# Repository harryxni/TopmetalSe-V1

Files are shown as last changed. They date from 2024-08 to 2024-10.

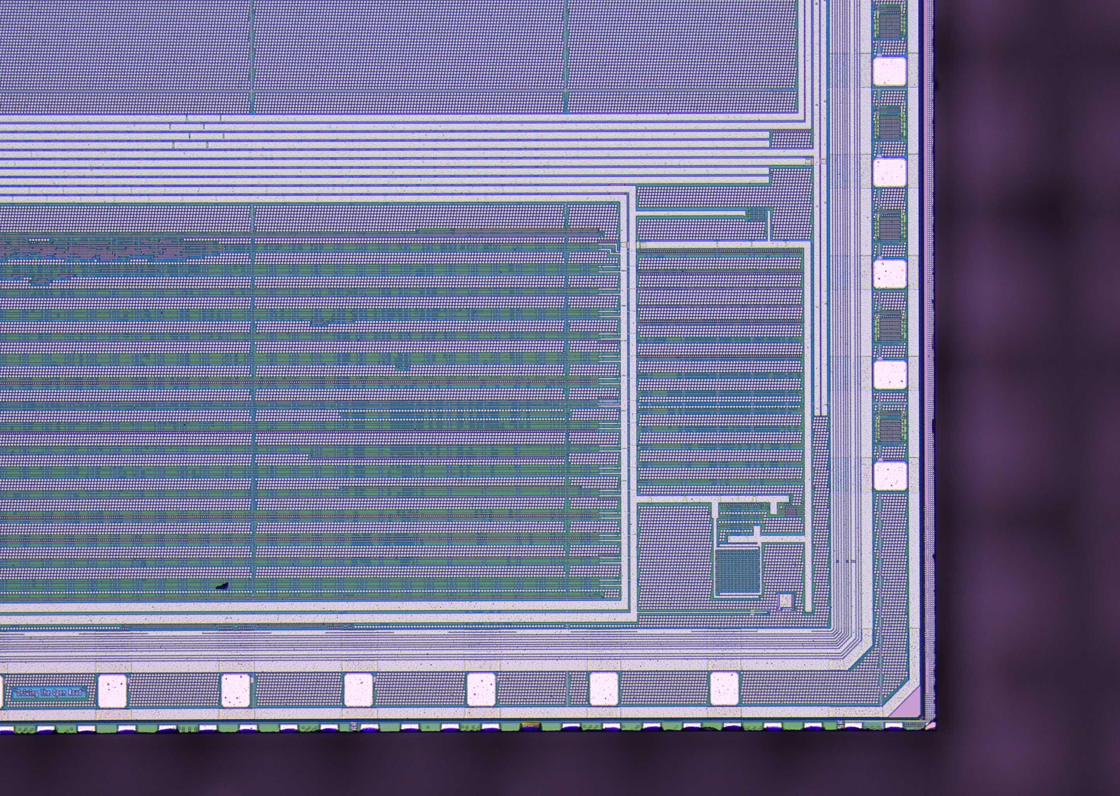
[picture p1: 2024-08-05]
Hardware/Images/chip_microscope_pictures/riscv.jpg

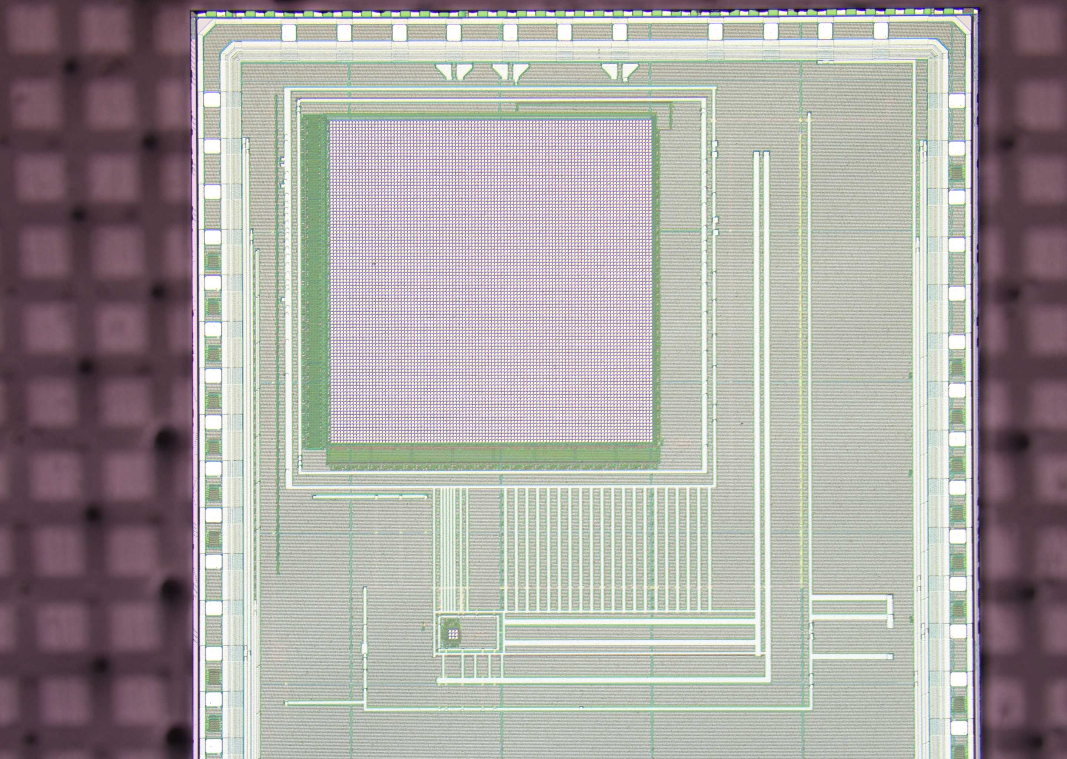
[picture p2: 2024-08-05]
Hardware/Images/chip_microscope_pictures/full.jpg

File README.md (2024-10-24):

# TopmetalSe-V1
This repo stores almost all of the info to run and understand the TopmetalSe

The directories here should be pretty self-explanatory honestly. 

If you want to learn how to run the chip, please look at Hardware and Firmware.

If you want to learn how well the chip performs and see examples, please look at Results.

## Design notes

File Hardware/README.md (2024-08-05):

# Hardware 
This directory contains the design files for using and testing the TopmetalSe.

## Test PCB, the UW Caravel Test Board
This board is the primary board used for testing as it contains all of the electronics necessary for running the chip.

A large part of this board is concerned with running the [caravel SOC](https://caravel-harness.readthedocs.io/en/latest/index.html), which is a part of the chip that we ultimatly do not use much. However, it is important to know that we can communicate with it, if necessary. It can also be useful to test I/O connections and make sure the chip is powered on/works as expected. As a result, much of this board is copied over from the [efabless caravel boards](https://github.com/efabless/caravel_board). A lot of the communication with the caravel SOC is done over USB via the FTDI chip and requires the clock to be on. For actual chip testing, please solder a jumper over J4 to turn the clock off to reduce the electronic noise.

The other part of the board is concerned with running the TopmetalSe, which happens in three categories: biasing, clocking and readout. 

The biasing of the chip is handled via the [Texas Instruments DAC 8568](https://www.ti.com/product/DAC8568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), which is an 8 Channel Digital to Analog Conveter. That is, we send digital commands and it outputs an analog voltage. The digital communication part is handled by an external FPGA, and the commands are generated via [software bit banging](https://github.com/selena0vbb/TopmetalSe_Sequencer/blob/main/util/DAC_control.py). These analog voltages are used as a bias either to source/sink a current or as a voltage bias on a transistor gate. 

The clocking of the chip is entirely handled by the external FPGAa and its firmware, so please look elsewhere for that. In the PCB design files, there are level shifters on the clocking signals to shift from the FPGA 3.3V signals to what I had assumed to be the caravel's 1.8V logic levels. However, the caravel harness actually expects 3.3V signals, so these level shifters are not soldered on and a jumper wire is used to make these connections.

There are two output signals coming from the TopmetalSe, an output for the large array (LA) and an output for the small array (SA). Both of these signals are readout using an opamp on the PCB. 

## Carrier Boards
To connect to the chip, we use a collection of adapter boards. This allows us to hotswap in any chip we want for testing. Now, the topmetalSe comes in a variety of packages, each of which has its own unique carrier board to accomdate the package. The carrier board is then plugged into the test board via 50 mil pins.

__One design fault is that the carriers can easily be plugged in incorrectly, causing undesired shorts. Please double check the pins and lined up correctly and in the correct orientation, as the header pins are symmetric. This applies to all carrier boards but the M.2 adapter.__

### M.2 Adapter Board
EFabless provided us with many QFN packaged chips. QFN, or quad flat no-leads, is an industry standard package for chips. Inside, chips are wire bonded to the frame and then encapsulated in plastic. This means that the QFN packages provide us with all the electrical capabilities, but none of the charge-sensing aspects of our device. __Please use these QFN packages to test and play around with learning to run the circuit__. Because we have so many and everything is encapsulated, there is very little chance of damaging these devices.

The QFN packages are/can be soldered onto a M.2 breakout board. EFabless provides the (design files)[https://github.com/efabless/caravel_board/tree/main/hardware/breakout/caravel-M.2-card-QFN] for these, so please look there if you need to. If you need more, the QFN packages must be soldered onto more M.2 breakouts.

The M.2 breakout boards can be attached to our test board via the M.2 adapter board.

### Wire Bonded

For charge-sensing, we must use the bare dies. The wire bonded carrier boards are pretty simple, as the bond pads go in the same order as the bond pads on the chip. The one key is that __the wire bonded board must be ENEPIG coated (not ENIG)__. If you order more, please make sure of this.

### Flip Chip

### aSe Flip Chip

## FPGA
For the FPGA, we use an external [BASYS3 Board](https://digilent.com/shop/basys-3-artix-7-fpga-trainer-board-recommended-for-introductory-users/). It is connected to the test board via PMOD connectors. Now, there is a mistake in the PCB design where the PMOD headers are actually flipped, so you must be careful to flip the PMOD connectors. Please see the PCB layout for this as well as the labels on the PCB to make sure things are aligned (ie Pin 1 to Pin 1). The firmware for the FPGA is discussed elsewhere.

## Sapphire Interposer
In flip chip packages, the chip is bonded to a flat piece known as the interposer. It is made with a 200/300 um thick piece of sapphire, which has conductive traces patterned and deposited onto it (usually O(100) nm of Al and Au). The side with traces on it is the bottom side. The top side is used for aSe Deposition and contains a conductive mesh. There is also a window opening where the pixel array is, which we typically laser cut.

## Electronic Equipment

## Mechanical Parts

## TopmetalSe Design Files
The majority of the design files for the TopmetalSe-V1 are contained in a [separate repo](https://github.com/harryxni/TopMetalSe-OpenMPW6). I include some general files in this repo as a reference.

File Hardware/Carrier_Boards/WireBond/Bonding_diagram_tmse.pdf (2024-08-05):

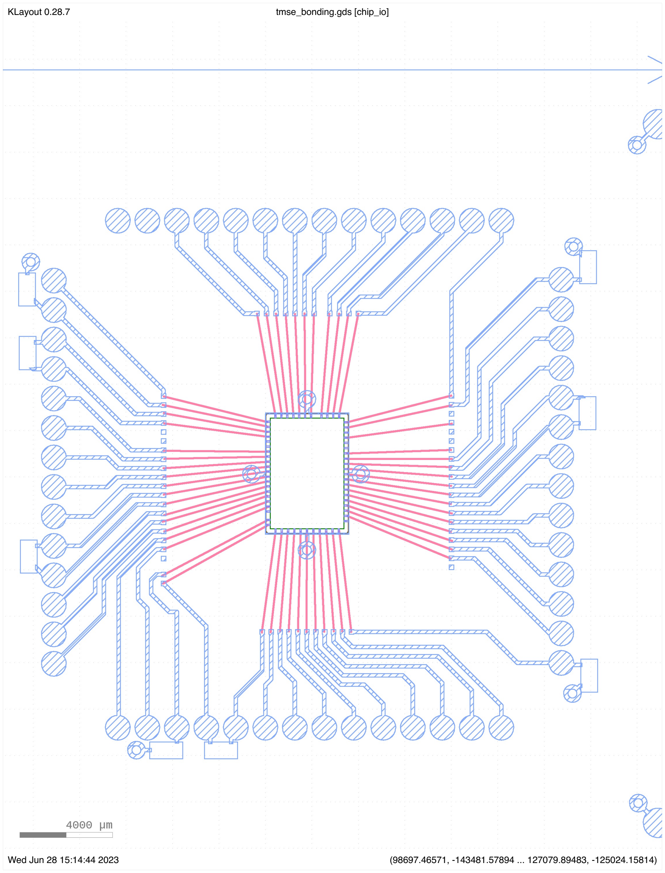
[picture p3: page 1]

KLayout 0.28.7 | tmse_bonding.gds [chip_io]
Wed Jun 28 15:14:44 2023 | (98697.46571, -143481.57894 ... 127079.89483, -125024.15814)

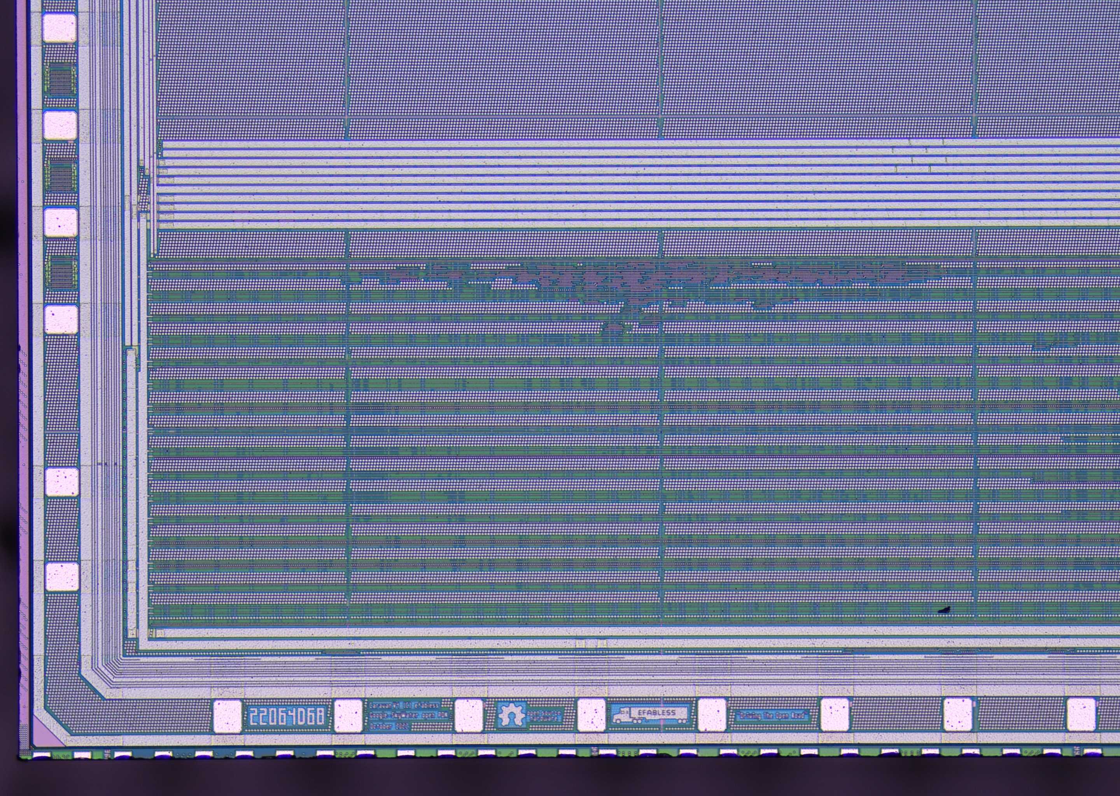
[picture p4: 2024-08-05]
Hardware/Images/chip_microscope_pictures/corner_pads.jpg

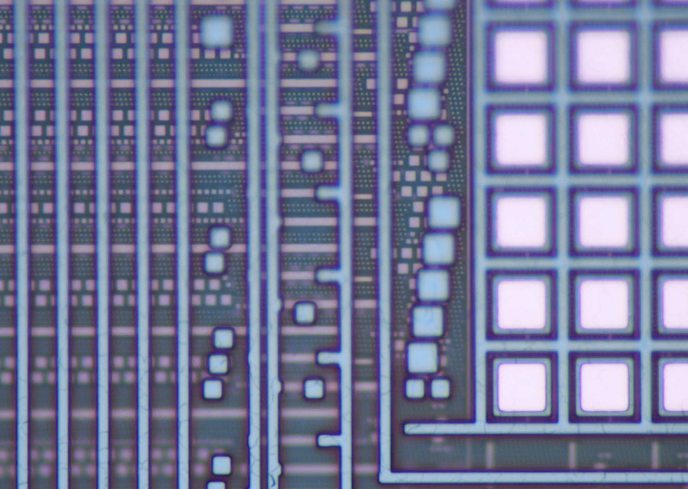
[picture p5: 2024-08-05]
Hardware/Images/chip_microscope_pictures/corner_large.jpg

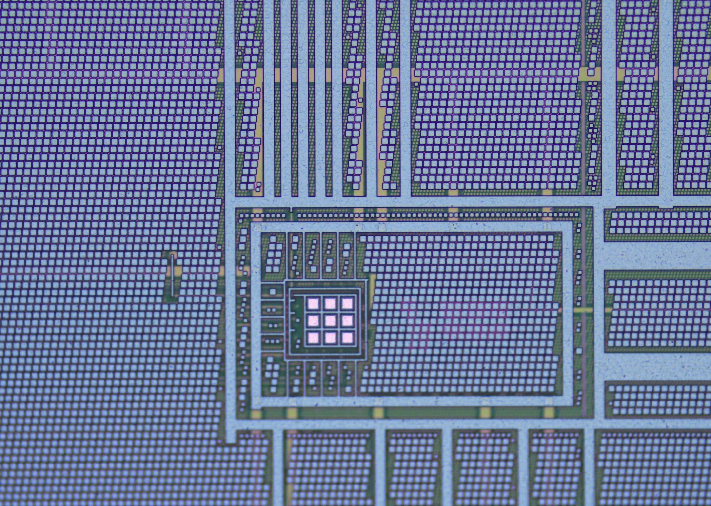
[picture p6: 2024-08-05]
Hardware/Images/chip_microscope_pictures/small_array.jpg

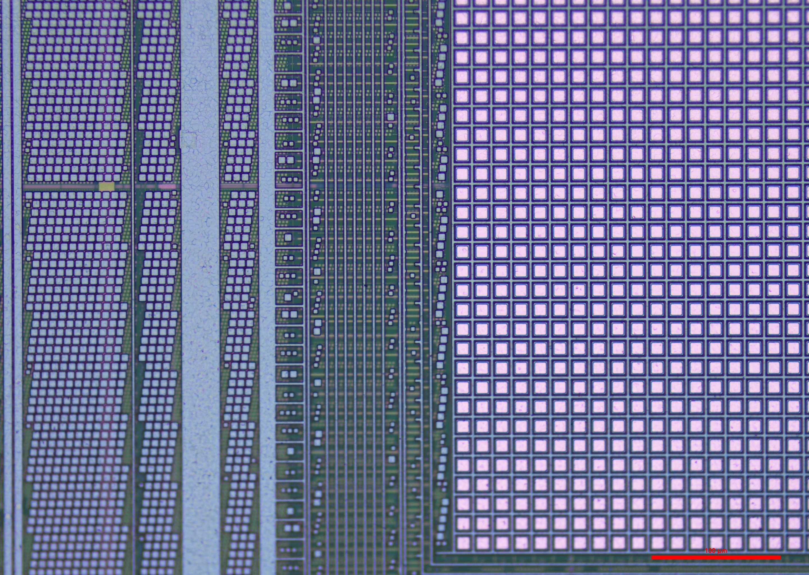
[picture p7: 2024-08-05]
Hardware/Images/chip_microscope_pictures/large_pixels.jpg

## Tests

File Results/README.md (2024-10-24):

# Results

In this directory, I am including the results of testing that we have done with the TopmetalSe.

## Guard Ring Pulsing for Charge Sensitive Amplifiers
An example of how we characterize the in-pixel charge sensitive amplifiers. This for a single pixel in a notebook.

We demonstrate the low-noise of these pixels.

## Visible Light Imaging
Testing the ability of the TopmetalSe to actually take images.

## Alpha Event Imaging
This result shows the TopmetalSe's ability to image external charge that lands on the pixel electrodes.

## Photoelectric Effect Imaging
Measuring the pixel array's collection efficiency by generating and measuring a calibrated amount of electrons external to the pixel array.

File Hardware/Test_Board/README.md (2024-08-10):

# Annotated PCB

In the annotated pcb image file, I have added some markers to explain any fixes that need to be made to the current test board. These are either where jumper cables must be soldered onto, or any components which should not be present.

On the left side of the board, the level shifters U12-U26 should not be used/soldered on. Instead, a jumper cable should be soldered between pads 3 and 4.

D4 should not be soldered on simply to remove a strong source of light which could ionize charge in the pixel array. It can useful to know if power is being supplied correctly, so use it in any initial testing phases. But, it should not be present for serious testing.

LA_Row_Clk should always be used and not Ser Tx (jumpered across).

VCCD should be connected to VCCD2 under the carrier board, so there should be a jumper wire between pins 43 and 27.

R23, R25 and R27 should not be present to prevent current flow along the voltage bias lines.

LDAC bar should always be jumpered.

The signals names for ROW and COL are actually switched. This is fixed in the FPGA software which controls these lines, but should be noted for any future iterations.

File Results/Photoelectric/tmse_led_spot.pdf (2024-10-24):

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

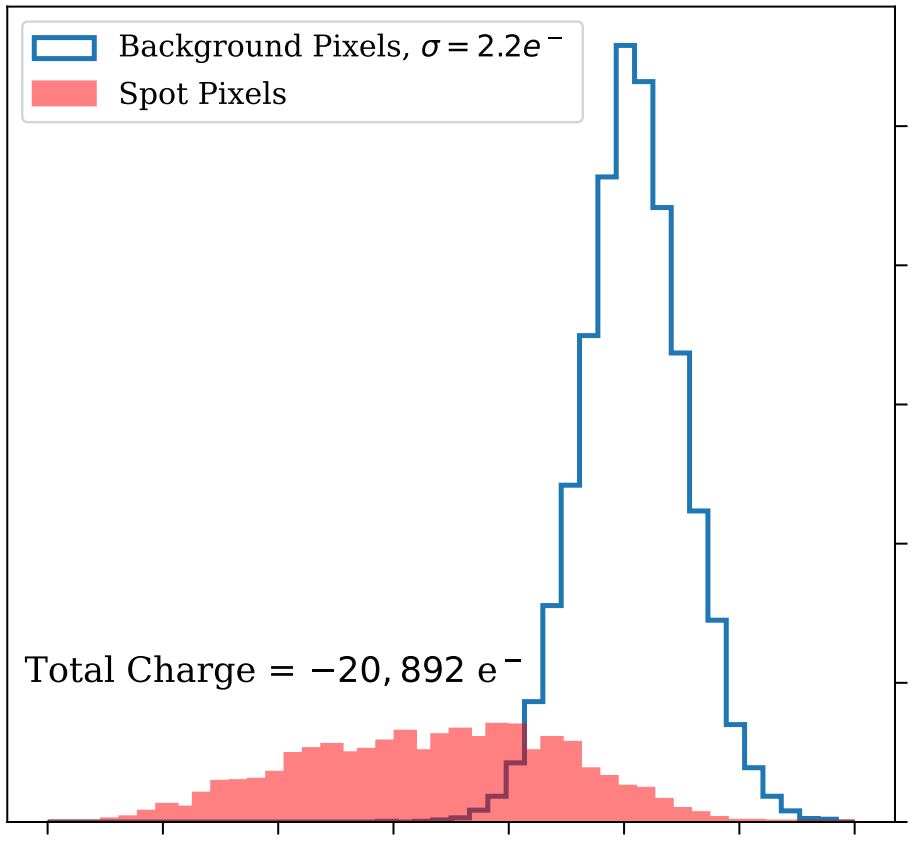
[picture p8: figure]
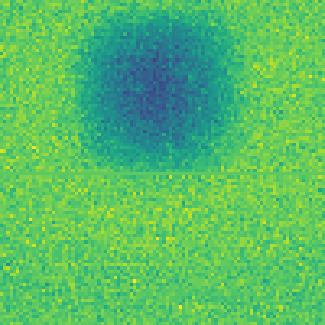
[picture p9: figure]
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

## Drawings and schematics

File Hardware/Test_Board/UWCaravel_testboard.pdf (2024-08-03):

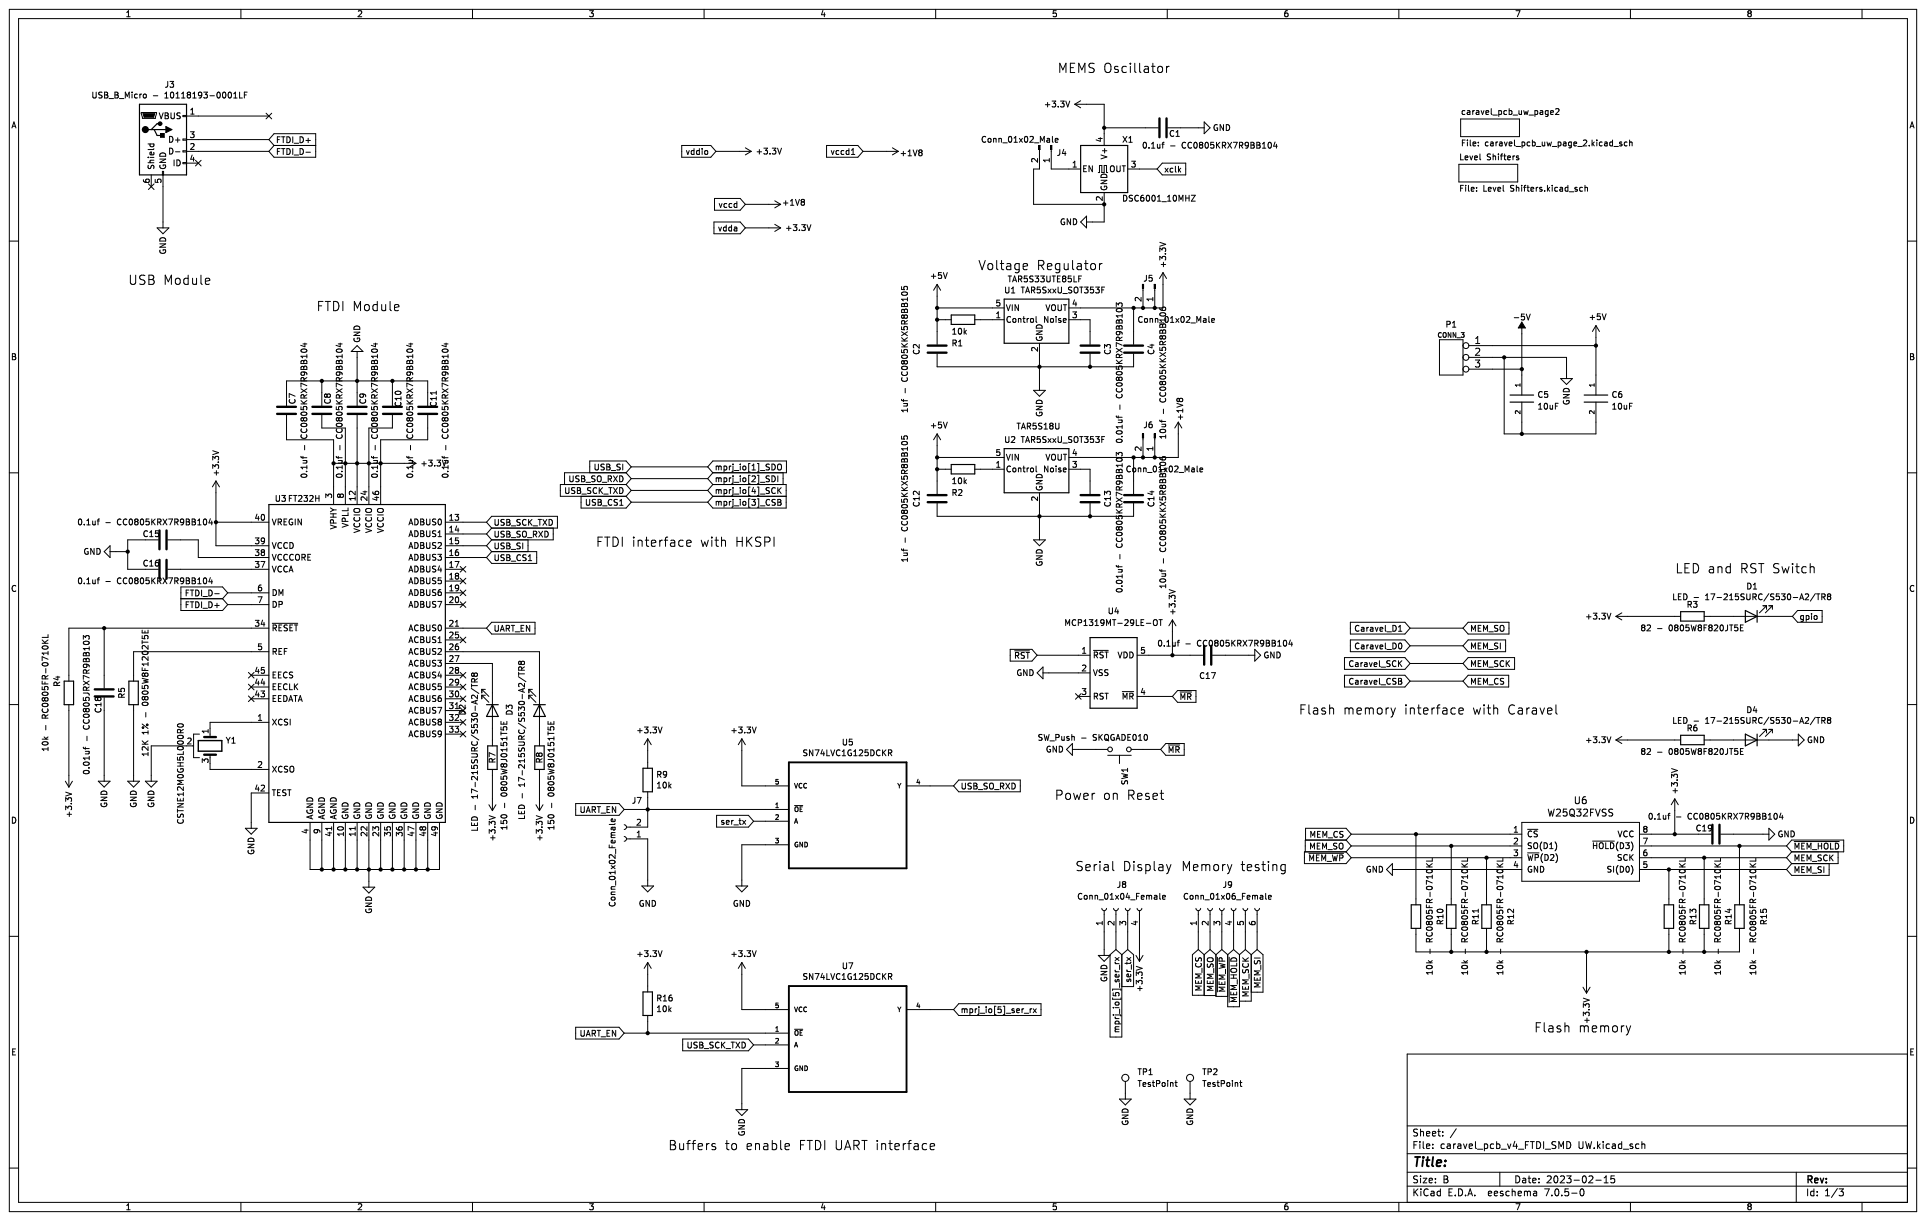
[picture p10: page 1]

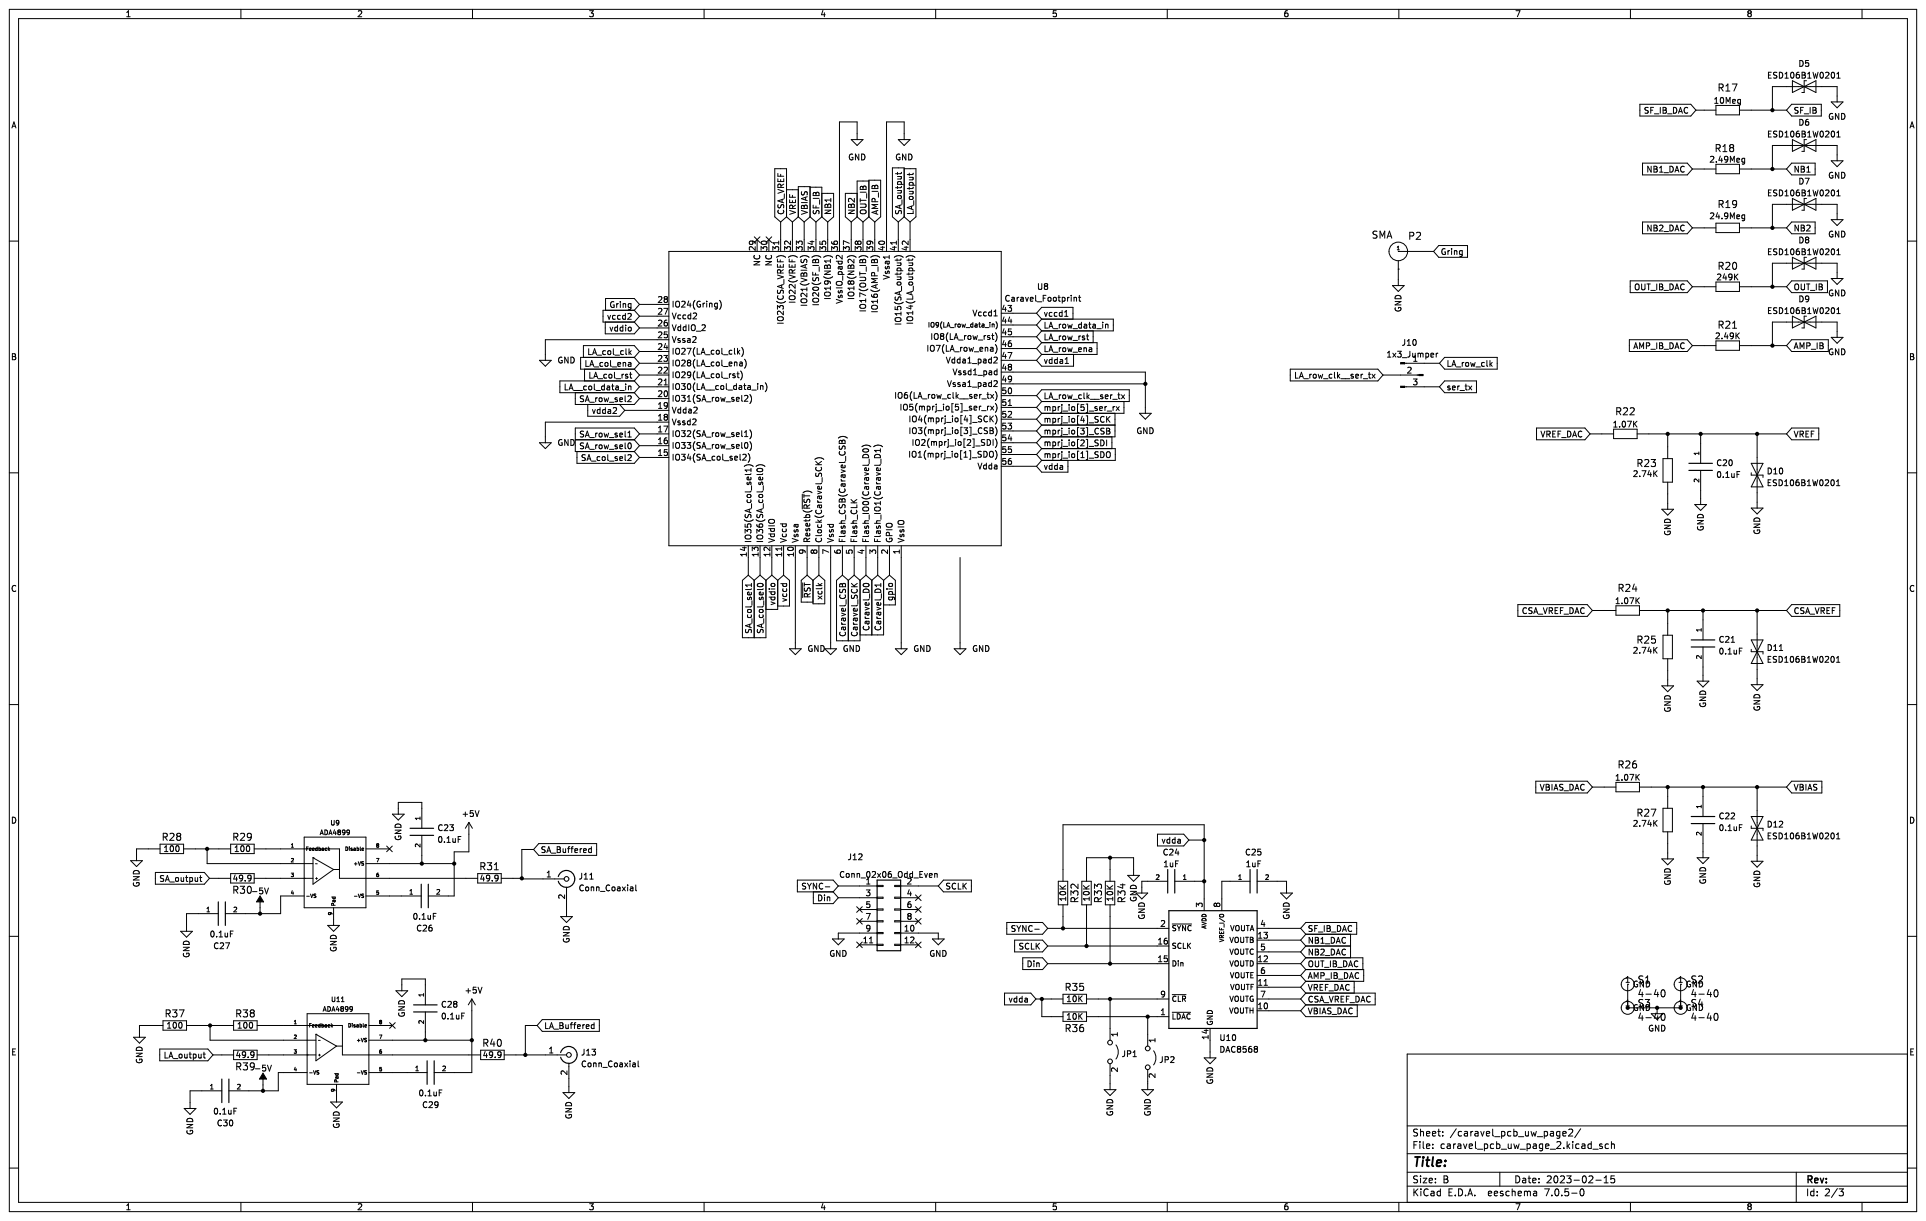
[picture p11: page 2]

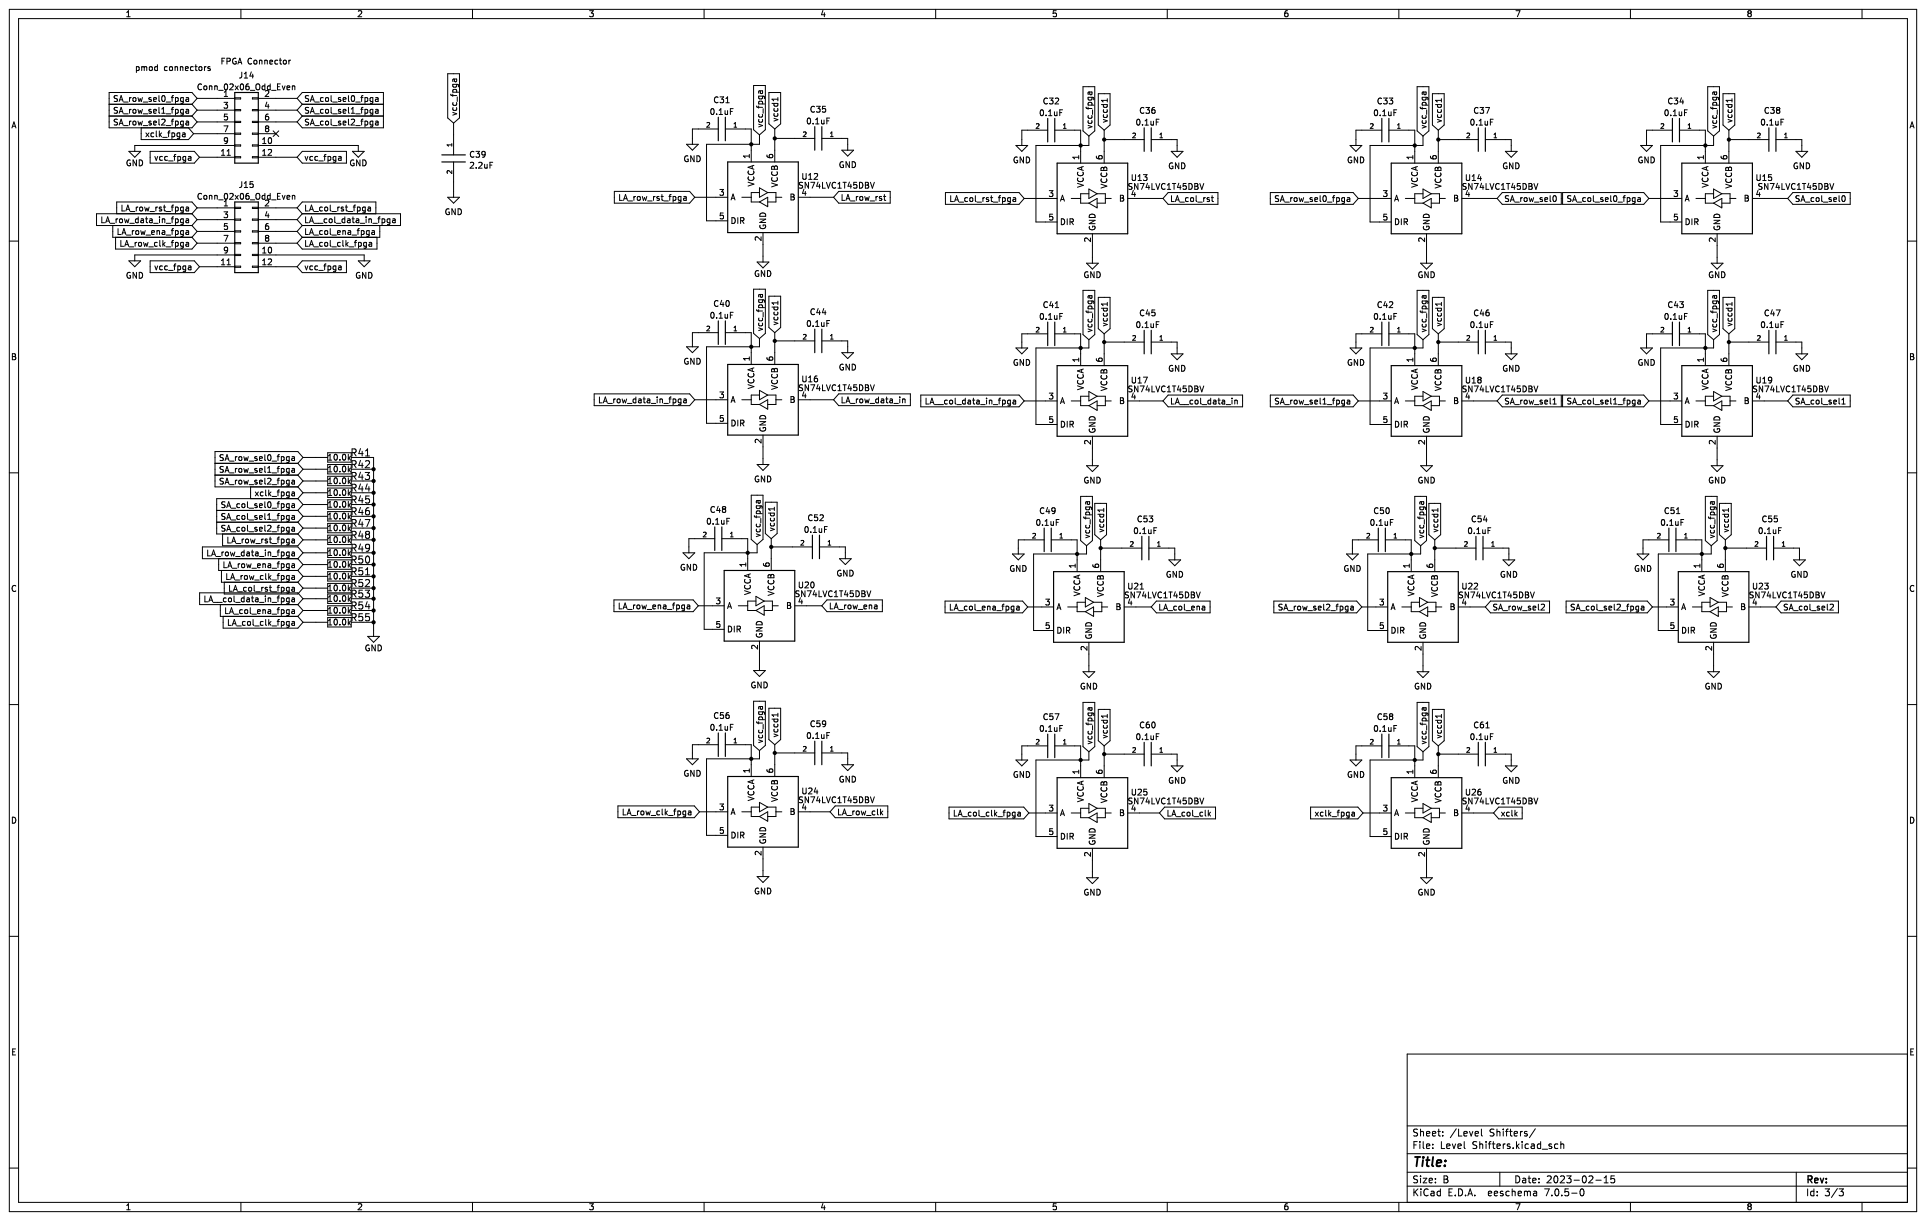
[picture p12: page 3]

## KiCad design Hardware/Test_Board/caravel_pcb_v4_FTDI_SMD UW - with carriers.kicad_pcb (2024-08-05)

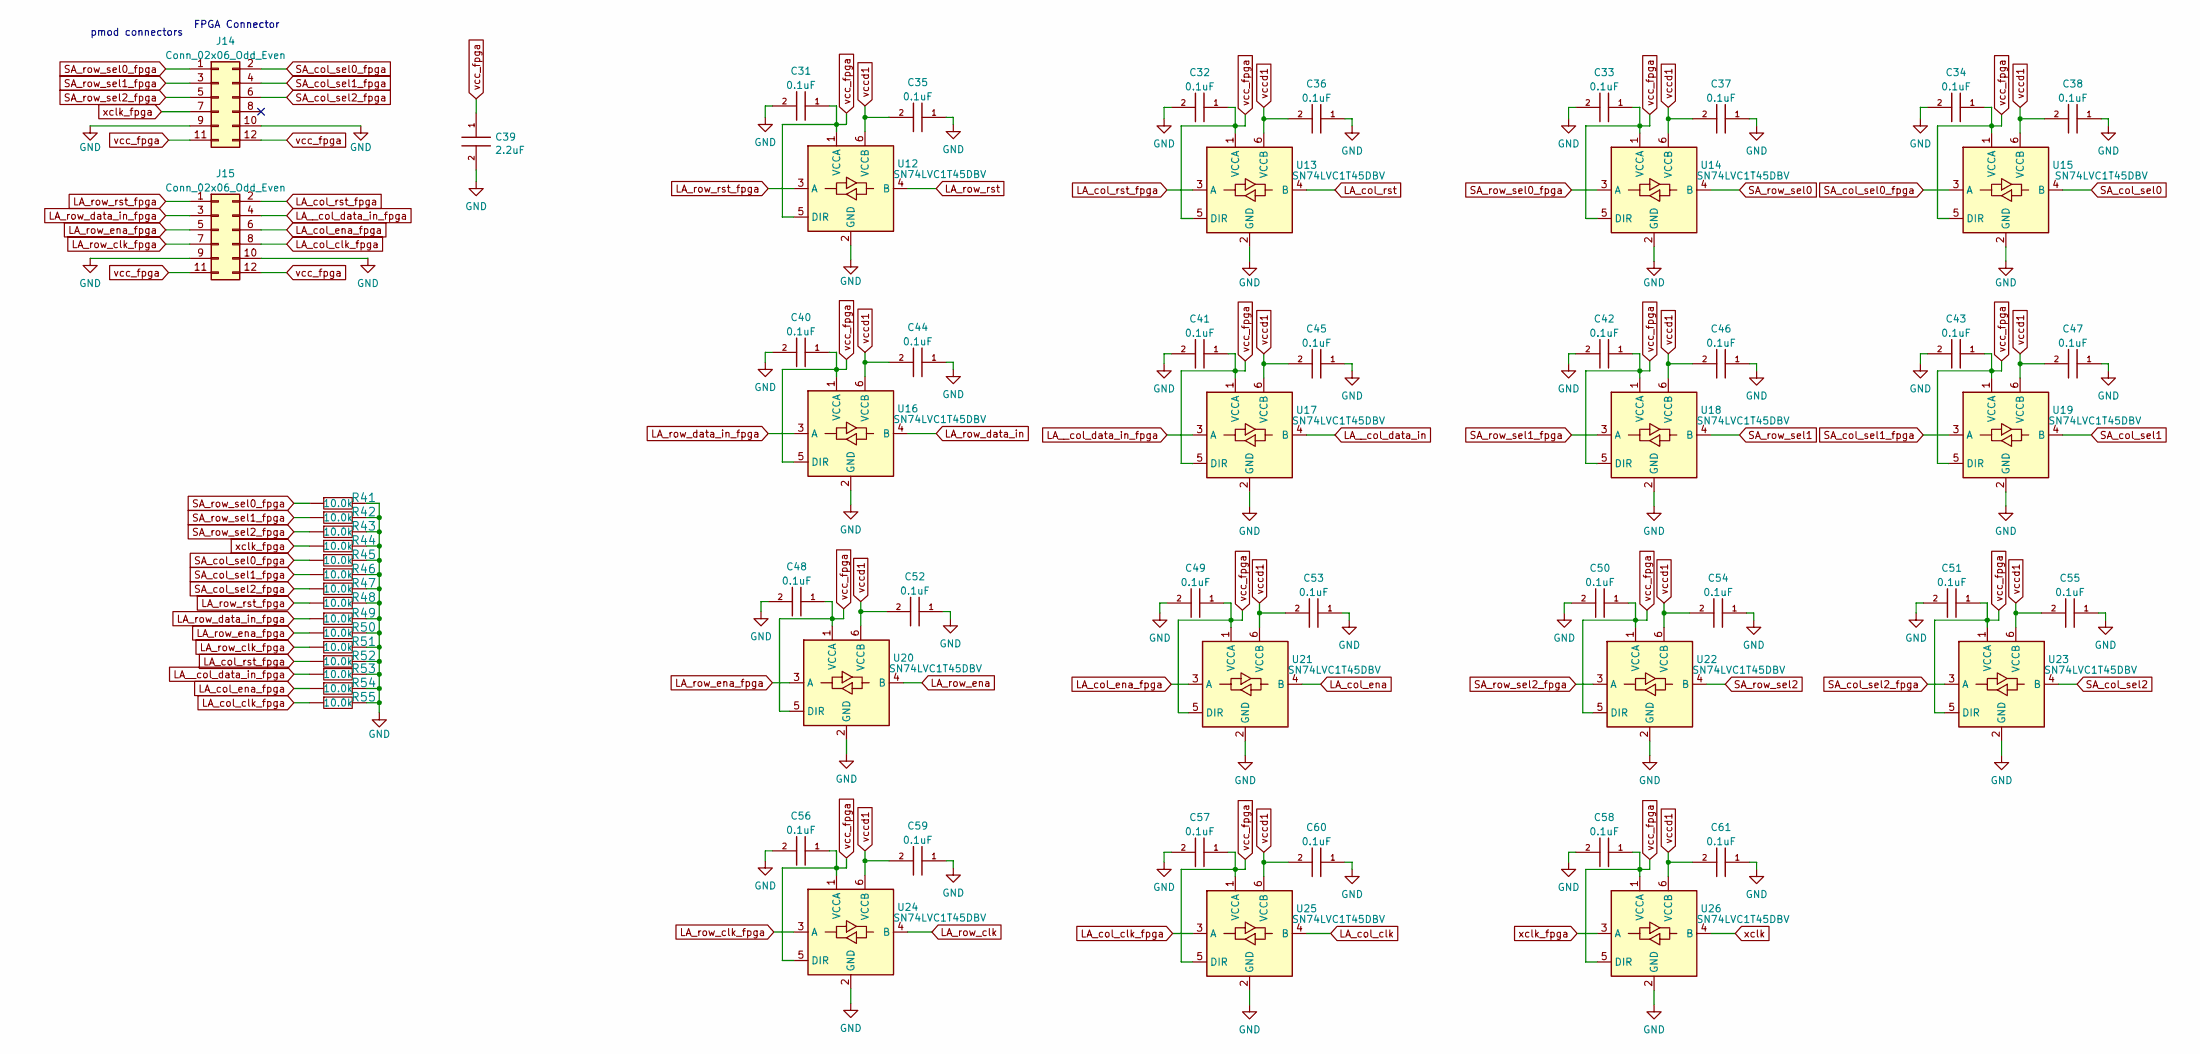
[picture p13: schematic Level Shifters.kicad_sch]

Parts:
C31, C32, C33, C34, C35, C36, C37, C38, C40, C41, C42, C43, C44, C45, C46, C47, C48, C49, C50, C51, C52, C53, C54, C55, C56, C57, C58, C59, C60, C61: 0.1uF; SM0603
C39: 2.2uF; SM0603
J14, J15: Conn_02x06_Odd_Even; PinHeader_2x06_P2.54mm_Horizontal
R41, R42, R43, R44, R45, R46, R47, R48, R49, R50, R51, R52, R53, R54, R55: 10.0k; SM0603
U12, U13, U14, U15, U16, U17, U18, U19, U20, U21, U22, U23, U24, U25, U26: SN74LVC1T45DBV; SOT-23-6

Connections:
LA__col_data_in: U17.4 (B); also elsewhere on the board
LA__col_data_in_fpga: J15.4, R53.1, U17.3 (A)
LA_col_clk: U25.4 (B); also elsewhere on the board
LA_col_clk_fpga: J15.8, R55.1, U25.3 (A)
LA_col_ena: U21.4 (B); also elsewhere on the board
LA_col_ena_fpga: J15.6, R54.1, U21.3 (A)
LA_col_rst: U13.4 (B); also elsewhere on the board
LA_col_rst_fpga: J15.2, R52.1, U13.3 (A)
LA_row_clk: U24.4 (B); also elsewhere on the board
LA_row_clk_fpga: J15.7, R51.1, U24.3 (A)
LA_row_data_in: U16.4 (B); also elsewhere on the board
LA_row_data_in_fpga: J15.3, R49.1, U16.3 (A)
LA_row_ena: U20.4 (B); also elsewhere on the board
LA_row_ena_fpga: J15.5, R50.1, U20.3 (A)
LA_row_rst: U12.4 (B); also elsewhere on the board
LA_row_rst_fpga: J15.1, R48.1, U12.3 (A)
SA_col_sel0: U15.4 (B); also elsewhere on the board
SA_col_sel0_fpga: J14.2, R45.1, U15.3 (A)
SA_col_sel1: U19.4 (B); also elsewhere on the board
SA_col_sel1_fpga: J14.4, R46.1, U19.3 (A)
SA_col_sel2: U23.4 (B); also elsewhere on the board
SA_col_sel2_fpga: J14.6, R47.1, U23.3 (A)
SA_row_sel0: U14.4 (B); also elsewhere on the board
SA_row_sel0_fpga: J14.1, R41.1, U14.3 (A)
SA_row_sel1: U18.4 (B); also elsewhere on the board
SA_row_sel1_fpga: J14.3, R42.1, U18.3 (A)
SA_row_sel2: U22.4 (B); also elsewhere on the board
SA_row_sel2_fpga: J14.5, R43.1, U22.3 (A)
vcc_fpga: C31.1, C32.1, C33.1, C34.1, C39.1, C40.1, C41.1, C42.1, C43.1, C48.1, C49.1, C50.1, C51.1, C56.1, C57.1, C58.1, J14.11, J14.12, J15.11, J15.12, U12.1 (VCCA), U12.5 (DIR), U13.1 (VCCA), U13.5 (DIR), U14.1 (VCCA), U14.5 (DIR), U15.1 (VCCA), U15.5 (DIR), U16.1 (VCCA), U16.5 (DIR), U17.1 (VCCA), U17.5 (DIR), U18.1 (VCCA), U18.5 (DIR), U19.1 (VCCA), U19.5 (DIR), U20.1 (VCCA), U20.5 (DIR), U21.1 (VCCA), U21.5 (DIR), U22.1 (VCCA), U22.5 (DIR), U23.1 (VCCA), U23.5 (DIR), U24.1 (VCCA), U24.5 (DIR), U25.1 (VCCA), U25.5 (DIR), U26.1 (VCCA), U26.5 (DIR)
vccd: C35.2, C36.2, C37.2, C38.2, C44.2, C45.2, C46.2, C47.2, C52.2, C53.2, C54.2, C55.2, C59.2, C60.2, C61.2, U12.6 (VCCB), U13.6 (VCCB), U14.6 (VCCB), U15.6 (VCCB), U16.6 (VCCB), U17.6 (VCCB), U18.6 (VCCB), U19.6 (VCCB), U20.6 (VCCB), U21.6 (VCCB), U22.6 (VCCB), U23.6 (VCCB), U24.6 (VCCB), U25.6 (VCCB), U26.6 (VCCB); also elsewhere on the board
xclk: U26.4 (B); also elsewhere on the board
xclk_fpga: J14.7, R44.1, U26.3 (A)

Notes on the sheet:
pmod connectors
FPGA Connector

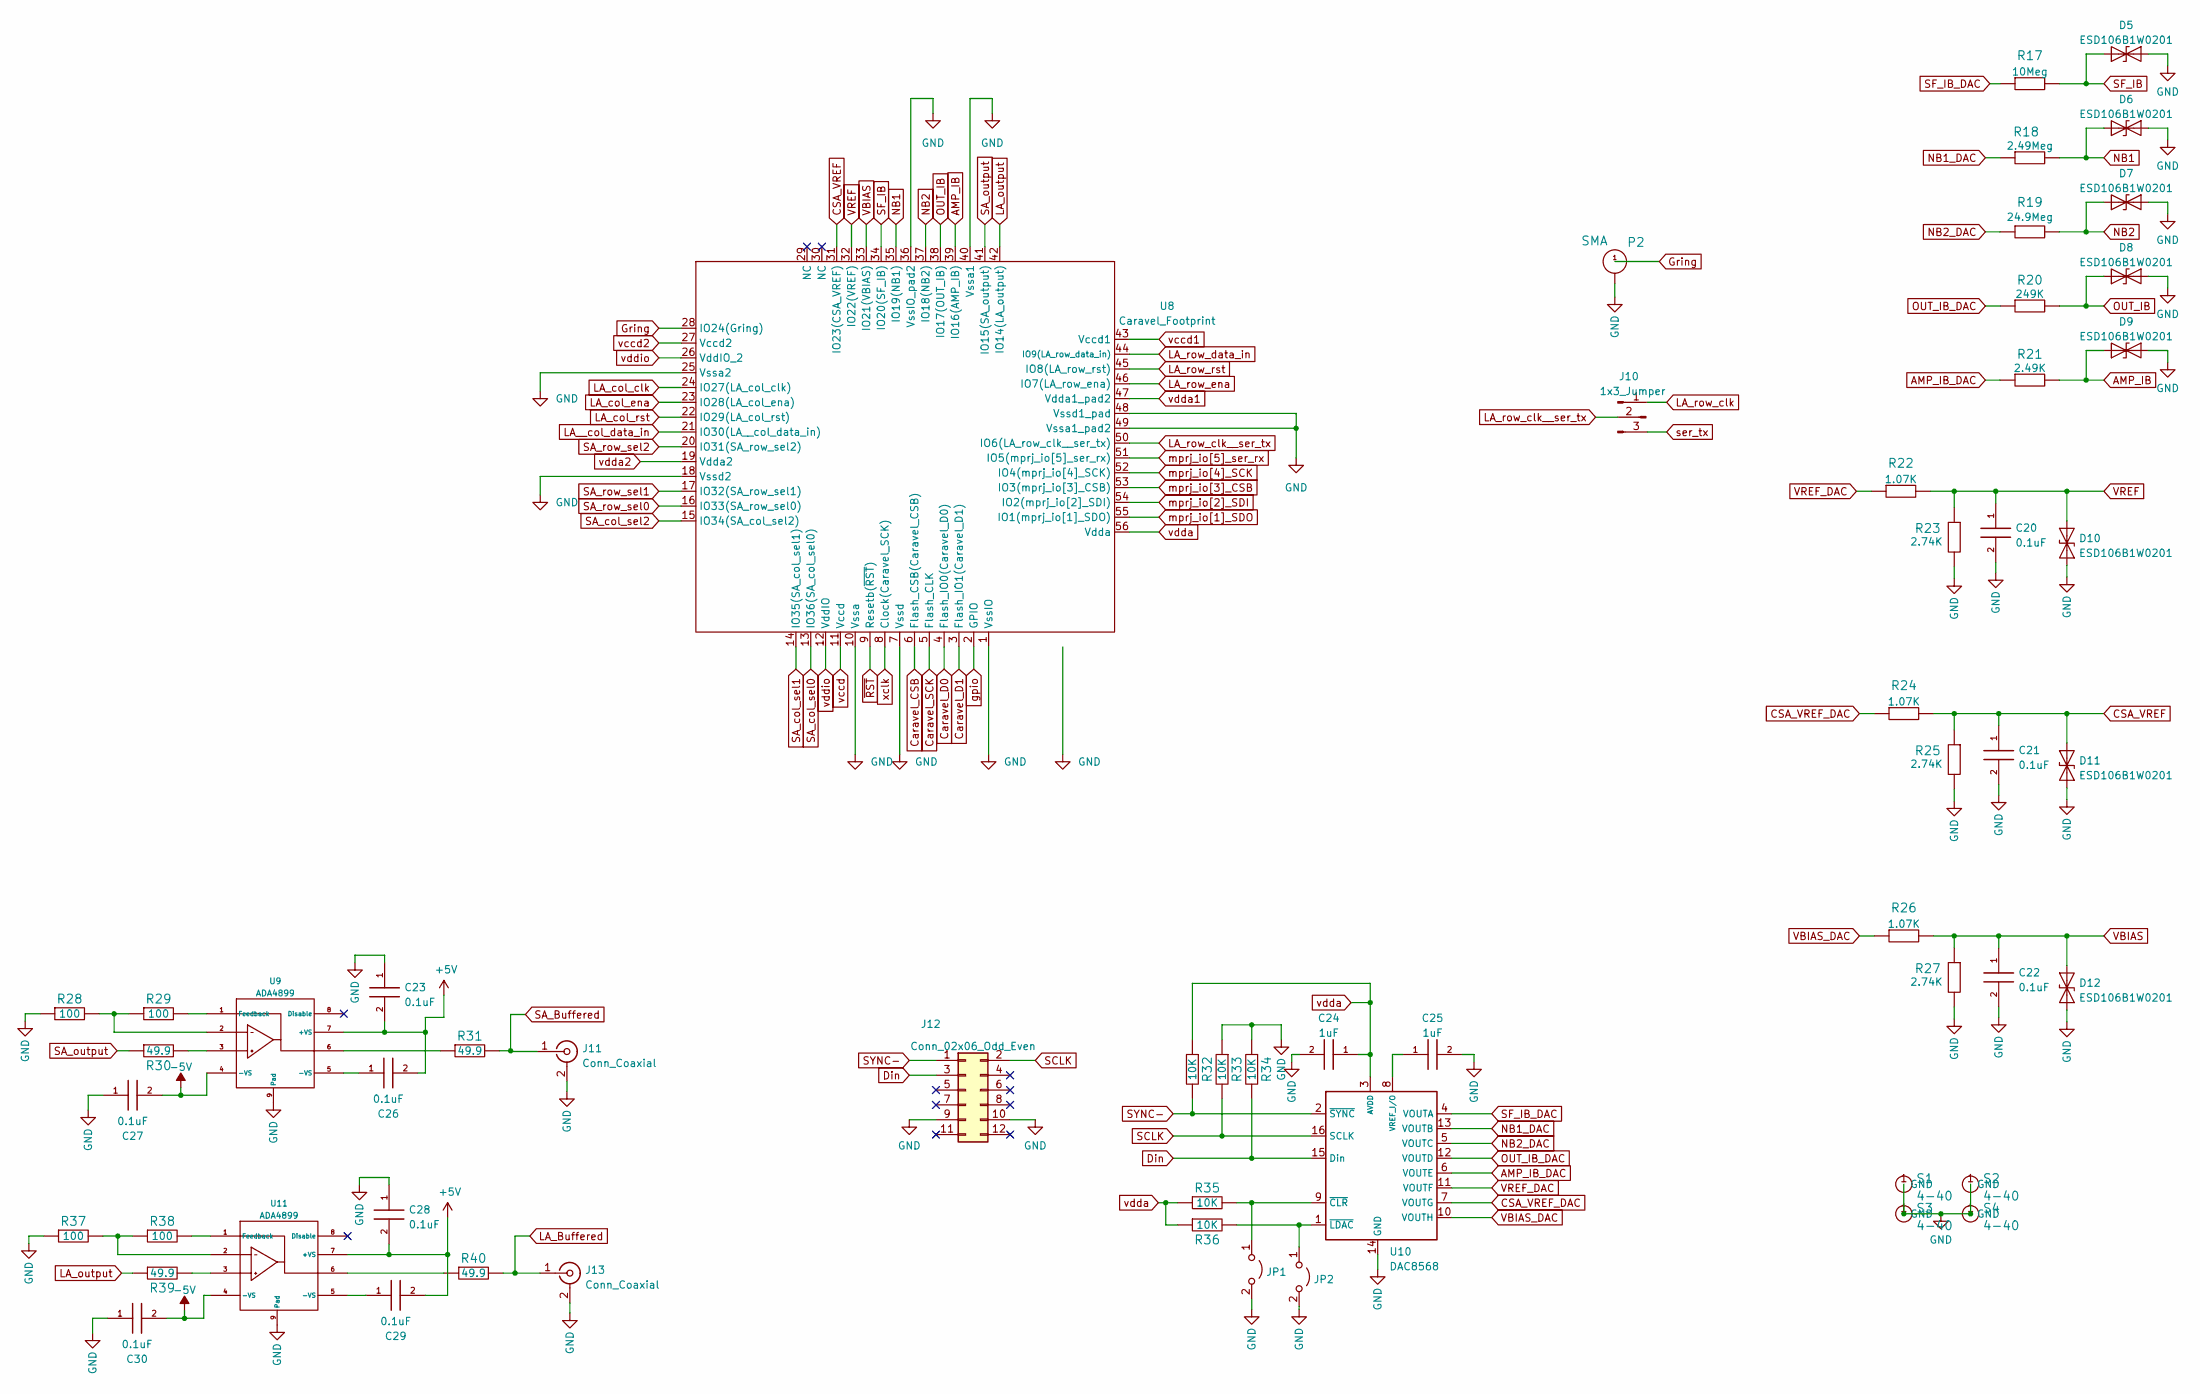
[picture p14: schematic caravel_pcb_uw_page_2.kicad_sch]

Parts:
C20, C21, C22, C23, C26, C27, C28, C29, C30: 0.1uF; SM0603
C24, C25: 1uF; SM0603
D5, D6, D7, D8, D9, D10, D11, D12: ESD106B1W0201; D_SOD-923
J10: 1x3_Jumper; SIL-3
J11, J13: Conn_Coaxial; SMA
J12: Conn_02x06_Odd_Even; PinHeader_2x06_P2.54mm_Horizontal
JP1, JP2: Jumper_2_Open; SIL-2
P2: SMA
R17: 10Meg; SM0603
R18: 2.49Meg; SM0603
R19: 24.9Meg; SM0603
R20: 249K; SM0603
R21: 2.49K; SM0603
R22, R24, R26: 1.07K; SM0603
R23, R25, R27: 2.74K; SM0603
R28, R29, R37, R38: 100; SM0603
R30, R31, R39, R40: 49.9; SM0603
R32, R33, R34, R35, R36: 10K; SM0603
S1, S2, S3, S4: 4-40; 4-40_Reduced
U8: Caravel_Footprint; Caravel_Carrier_Footprint
U9, U11: ADA4899; SO-8_EP
U10: DAC8568; TSSOP-16_4.4x5mm_P0.65mm

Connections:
AMP_IB: D9.1 (A1), R21.2, U8.39 (IO16(AMP_IB))
AMP_IB_DAC: R21.1, U10.6 (VOUTE)
CSA_VREF: C21.1, D11.1 (A1), R24.2, R25.1, U8.31 (IO23(CSA_VREF))
CSA_VREF_DAC: R24.1, U10.7 (VOUTG)
Caravel_CSB: U8.6 (Flash_CSB(Caravel_CSB)); also elsewhere on the board
Caravel_D0: U8.4 (Flash_IO0(Caravel_D0)); also elsewhere on the board
Caravel_D1: U8.3 (Flash_IO1(Caravel_D1)); also elsewhere on the board
Caravel_SCK: U8.5 (Flash_CLK); also elsewhere on the board
Din: J12.3, R34.2, U10.15 (Din)
Gring: P2.1, U8.28 (IO24(Gring))
LA_Buffered: J13.1 (In), R40.2
LA__col_data_in: U8.21 (IO30(LA__col_data_in)); also elsewhere on the board
LA_col_clk: U8.24 (IO27(LA_col_clk)); also elsewhere on the board
LA_col_ena: U8.23 (IO28(LA_col_ena)); also elsewhere on the board
LA_col_rst: U8.22 (IO29(LA_col_rst)); also elsewhere on the board
LA_output: R39.1, U8.42 (IO14(LA_output))
LA_row_clk: J10.1; also elsewhere on the board
LA_row_clk__ser_tx: J10.2, U8.50 (IO6(LA_row_clk__ser_tx))
LA_row_data_in: U8.44 (IO9(LA_row_data_in)); also elsewhere on the board
LA_row_ena: U8.46 (IO7(LA_row_ena)); also elsewhere on the board
LA_row_rst: U8.45 (IO8(LA_row_rst)); also elsewhere on the board
NB1: D6.1 (A1), R18.2, U8.35 (IO19(NB1))
NB1_DAC: R18.1, U10.13 (VOUTB)
NB2: D7.1 (A1), R19.2, U8.37 (IO18(NB2))
NB2_DAC: R19.1, U10.5 (VOUTC)
unnamed: C25.1, U10.8 (VREF_I/O)
unnamed: C26.1, U9.5 (-VS)
unnamed: C29.1, U11.5 (-VS)
unnamed: JP1.1 (A), R35.2, U10.9 (~CLR)
unnamed: JP2.1 (A), R36.2, U10.1 (~LDAC)
unnamed: R28.2, R29.1, U9.2
unnamed: R29.2, U9.1 (Feedback)
unnamed: R30.2, U9.3
unnamed: R31.1, U9.6
unnamed: R37.2, R38.1, U11.2
unnamed: R38.2, U11.1 (Feedback)
unnamed: R39.2, U11.3
unnamed: R40.1, U11.6
OUT_IB: D8.1 (A1), R20.2, U8.38 (IO17(OUT_IB))
OUT_IB_DAC: R20.1, U10.12 (VOUTD)
SA_Buffered: J11.1 (In), R31.2
SA_col_sel0: U8.13 (IO36(SA_col_sel0)); also elsewhere on the board
SA_col_sel1: U8.14 (IO35(SA_col_sel1)); also elsewhere on the board
SA_col_sel2: U8.15 (IO34(SA_col_sel2)); also elsewhere on the board
SA_output: R30.1, U8.41 (IO15(SA_output))
SA_row_sel0: U8.16 (IO33(SA_row_sel0)); also elsewhere on the board
SA_row_sel1: U8.17 (IO32(SA_row_sel1)); also elsewhere on the board
SA_row_sel2: U8.20 (IO31(SA_row_sel2)); also elsewhere on the board
SCLK: J12.2, R33.2, U10.16 (SCLK)
SF_IB: D5.1 (A1), R17.2, U8.34 (IO20(SF_IB))
SF_IB_DAC: R17.1, U10.4 (VOUTA)
SYNC-: J12.1, R32.2, U10.2 (~SYNC)
USB_CS1: U8.53 (IO3(mprj_io[3]_CSB)); also elsewhere on the board
USB_SCK_TXD: U8.52 (IO4(mprj_io[4]_SCK)); also elsewhere on the board
USB_SI: U8.55 (IO1(mprj_io[1]_SDO)); also elsewhere on the board
USB_SO_RXD: U8.54 (IO2(mprj_io[2]_SDI)); also elsewhere on the board
VBIAS: C22.1, D12.1 (A1), R26.2, R27.1, U8.33 (IO21(VBIAS))
VBIAS_DAC: R26.1, U10.10 (VOUTH)
VREF: C20.1, D10.1 (A1), R22.2, R23.1, U8.32 (IO22(VREF))
VREF_DAC: R22.1, U10.11 (VOUTF)
gpio: U8.2 (GPIO); also elsewhere on the board
mprj_io[5]_ser_rx: U8.51 (IO5(mprj_io[5]_ser_rx)); also elsewhere on the board
ser_tx: J10.3; also elsewhere on the board
vccd: U8.11 (Vccd), U8.43 (Vccd1); also elsewhere on the board
vccd2: U8.27 (Vccd2)
vdda1: U8.47 (Vdda1_pad2)
vdda2: U8.19 (Vdda2)
xclk: U8.8 (Clock(Caravel_SCK)); also elsewhere on the board
~RST: U8.9 (Resetb(~RST)); also elsewhere on the board

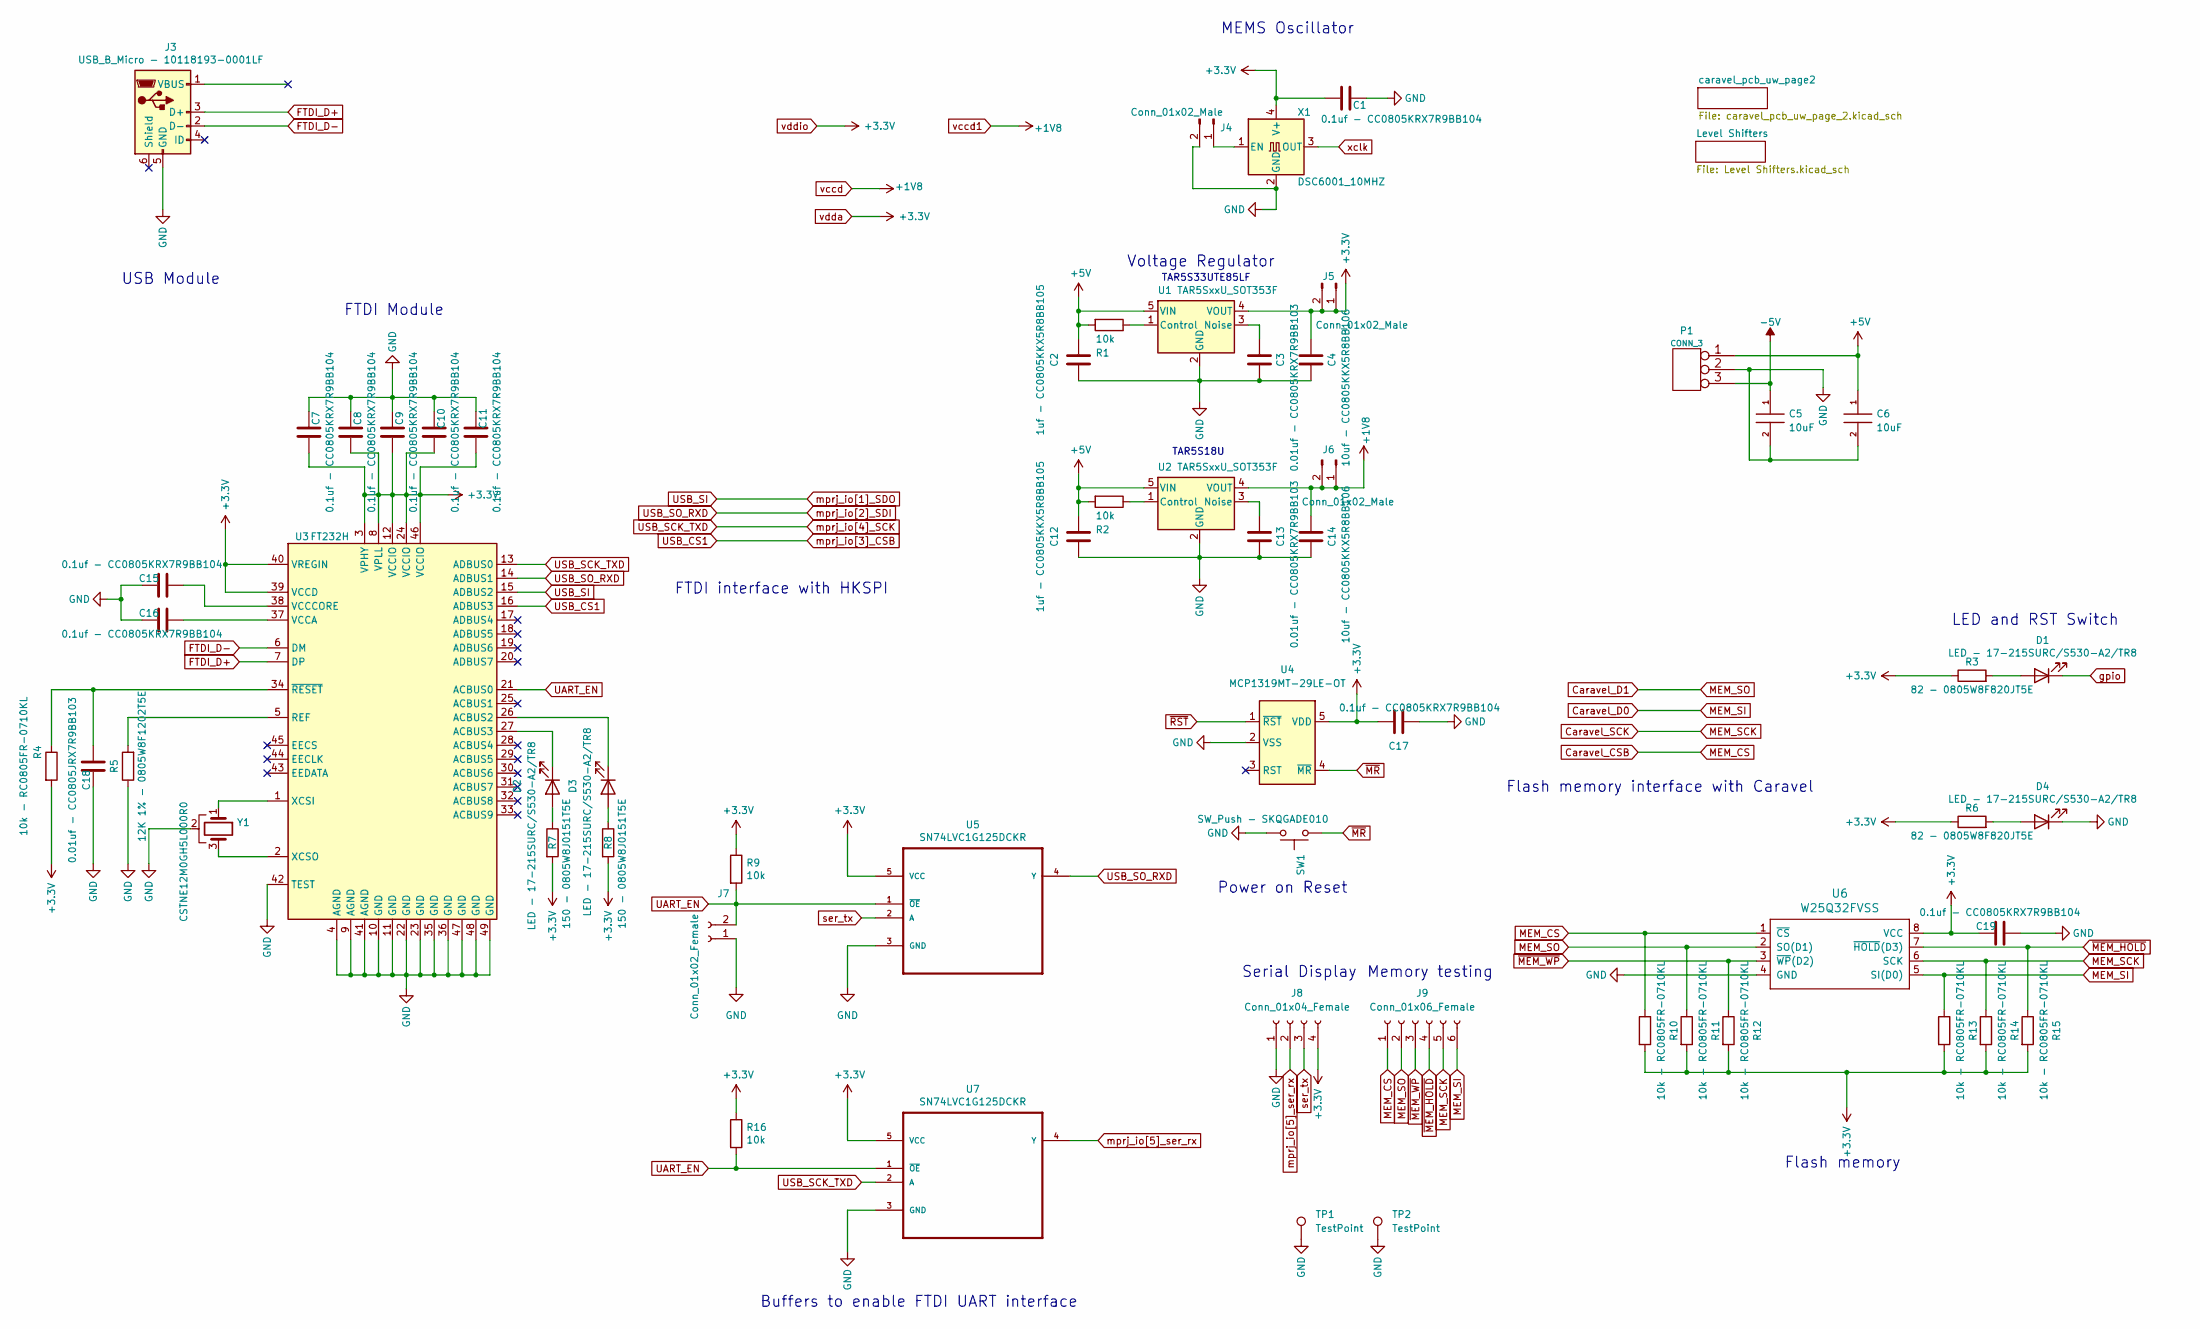
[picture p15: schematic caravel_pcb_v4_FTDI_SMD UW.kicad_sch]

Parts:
C1, C7, C8, C10, C11, C15, C16, C17, C19: 0.1uf - CC0805KRX7R9BB104; SM0603
C2, C12: 1uf - CC0805KKX5R8BB105; SM0603
C3, C13: 0.01uf - CC0805KRX7R9BB103; SM0603
C4, C14: 10uf - CC0805KKX5R8BB106; SM0603
C5, C6: 10uF; SM0603
C9: 0.1uf - CC0805KRX7R9BB104; SM0402
C18: 0.01uf - CC0805JRX7R9BB103; SM0603
D1, D2, D3, D4: LED - 17-215SURC/S530-A2/TR8; LED_1206_3216Metric
J3: USB_B_Micro - 10118193-0001LF; FCI_10118193-0001LF
J4, J5, J6: Conn_01x02_Male; PinHeader_1x02_P2.54mm_Vertical
J7: Conn_01x02_Female; PinHeader_1x02_P2.54mm_Vertical
J8: Conn_01x04_Female; PinHeader_1x04_P2.54mm_Vertical
J9: Conn_01x06_Female; PinHeader_1x06_P2.54mm_Vertical
P1: CONN_3; SIL-3_RA
R1, R2, R9, R16: 10k; SM0603
R3, R6: 82 - 0805W8F820JT5E; SM0603
R4, R10, R11, R12, R13, R14, R15: 10k - RC0805FR-0710KL; SM0603
R5: 12K 1% - 0805W8F1202T5E; SM0402
R7, R8: 150 - 0805W8J0151T5E; SM0603
SW1: SW_Push - SKQGADE010; SW4-SMD-5.2X5.2X1.5MM
TP1, TP2: TestPoint; TestPoint_Bridge_Pitch2.54mm_Drill1.0mm
U1, U2: TAR5SxxU_SOT353F; SOT-353_SC-70-5_Handsoldering
U3: FT232H; QFN-48-1EP_8x8mm_P0.5mm_EP6.2x6.2mm
U4: MCP1319MT-29LE-OT; SOT23-5
U5, U7: SN74LVC1G125DCKR; SOT23-5
U6: W25Q32FVSS; SOIC127P790X216-8N
X1: DSC6001_10MHZ; DSC6001JE1A-010.0000
Y1: CSTNE12M0GH5L000R0

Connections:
/Vdda: U1.56 (Vdda); also elsewhere on the board
Caravel_CSB: J9.1, R10.1, U6.1 (~CS); also elsewhere on the board
Caravel_D0: J9.6, R13.1, U6.5 (SI(D0)); also elsewhere on the board
Caravel_D1: J9.2, R11.1, U6.2 (SO(D1)); also elsewhere on the board
Caravel_SCK: J9.5, R14.1, U6.6 (SCK); also elsewhere on the board
FTDI_D+: J3.3 (D+), U3.7 (DP)
FTDI_D-: J3.2 (D-), U3.6 (DM)
unnamed: C13.1, U2.3 (Noise)
unnamed: C15.2, U3.38 (VCCCORE)
unnamed: C16.2, U3.37 (VCCA)
unnamed: C18.2, R4.1, U3.34 (~RESET)
unnamed: D1.2 (A), R3.2
unnamed: D2.1 (K), U3.27 (ACBUS3)
unnamed: D2.2 (A), R7.1
unnamed: D3.1 (K), U3.26 (ACBUS2)
unnamed: D3.2 (A), R8.1
unnamed: D4.2 (A), R6.2
unnamed: J4.1, X1.1 (EN)
unnamed: R2.1, U2.1 (Control)
unnamed: R5.2, U3.5 (REF)
unnamed 62: U1.VssIO; also elsewhere on the board
unnamed 63: U1.6 (Flash_CSB(Caravel_CSB)), U1.Flash_CSB (Flash_CSB(Caravel_CSB)); also elsewhere on the board
unnamed 64: U1.Vssd; also elsewhere on the board
unnamed 65: U1.8 (Clock(Caravel_SCK)), U1.Clock (Clock(Caravel_SCK)); also elsewhere on the board
unnamed 66: U1.9 (Resetb(~RST)), U1.Resetb (Resetb(~RST)); also elsewhere on the board
unnamed 67: U1.Vssa; also elsewhere on the board
unnamed 68: U1.Vccd; also elsewhere on the board
unnamed 69: U1.VddIO; also elsewhere on the board
unnamed 70: U1.13 (IO36(SA_col_sel0)), U1.IO36 (IO36(SA_col_sel0)); also elsewhere on the board
unnamed 71: U1.14 (IO35(SA_col_sel1)), U1.IO35 (IO35(SA_col_sel1)); also elsewhere on the board
unnamed 72: U1.15 (IO34(SA_col_sel2)), U1.IO34 (IO34(SA_col_sel2)); also elsewhere on the board
unnamed 73: U1.16 (IO33(SA_row_sel0)), U1.IO33 (IO33(SA_row_sel0)); also elsewhere on the board
unnamed 74: U1.17 (IO32(SA_row_sel1)), U1.IO32 (IO32(SA_row_sel1)); also elsewhere on the board
unnamed 75: U1.Vssd2; also elsewhere on the board
unnamed 76: U1.Vdda2; also elsewhere on the board
unnamed 77: U1.20 (IO31(SA_row_sel2)), U1.IO31 (IO31(SA_row_sel2)); also elsewhere on the board
unnamed 78: U1.21 (IO30(LA__col_data_in)), U1.IO30 (IO30(LA__col_data_in)); also elsewhere on the board
unnamed 79: U1.22 (IO29(LA_col_rst)), U1.IO29 (IO29(LA_col_rst)); also elsewhere on the board
unnamed 80: U1.23 (IO28(LA_col_ena)), U1.IO28 (IO28(LA_col_ena)); also elsewhere on the board
unnamed 81: U1.24 (IO27(LA_col_clk)), U1.IO27 (IO27(LA_col_clk)); also elsewhere on the board
unnamed 82: U1.Vssa2; also elsewhere on the board
unnamed 83: U1.VddIO_2; also elsewhere on the board
unnamed 84: U1.Vccd2; also elsewhere on the board
unnamed 85: U1.28 (IO24(Gring)), U1.IO24 (IO24(Gring)); also elsewhere on the board
unnamed 86: U1.31 (IO23(CSA_VREF)), U1.IO23 (IO23(CSA_VREF)); also elsewhere on the board
unnamed 87: U1.32 (IO22(VREF)), U1.IO22 (IO22(VREF)); also elsewhere on the board
unnamed 88: U1.33 (IO21(VBIAS)), U1.IO21 (IO21(VBIAS)); also elsewhere on the board
unnamed 89: U1.34 (IO20(SF_IB)), U1.IO20 (IO20(SF_IB)); also elsewhere on the board
unnamed 90: U1.35 (IO19(NB1)), U1.IO19 (IO19(NB1)); also elsewhere on the board
unnamed 91: U1.VssIO_pad2; also elsewhere on the board
unnamed 92: U1.37 (IO18(NB2)), U1.IO18 (IO18(NB2)); also elsewhere on the board
unnamed 93: U1.38 (IO17(OUT_IB)), U1.IO17 (IO17(OUT_IB)); also elsewhere on the board
unnamed 94: U1.39 (IO16(AMP_IB)), U1.IO16 (IO16(AMP_IB)); also elsewhere on the board
unnamed 95: U1.Vssa1; also elsewhere on the board
unnamed 96: U1.41 (IO15(SA_output)), U1.IO15 (IO15(SA_output)); also elsewhere on the board
unnamed 97: U1.42 (IO14(LA_output)), U1.IO14 (IO14(LA_output)); also elsewhere on the board
unnamed 98: U1.Vccd1; also elsewhere on the board
unnamed 99: U1.44 (IO9(LA_row_data_in)), U1.IO9 (IO9(LA_row_data_in)); also elsewhere on the board
unnamed 100: U1.45 (IO8(LA_row_rst)), U1.IO8 (IO8(LA_row_rst)); also elsewhere on the board
unnamed 101: U1.46 (IO7(LA_row_ena)), U1.IO7 (IO7(LA_row_ena)); also elsewhere on the board
unnamed 102: U1.Vdda1_pad2; also elsewhere on the board
unnamed 103: U1.Vssd1_pad; also elsewhere on the board
unnamed 104: U1.Vssa1_pad2; also elsewhere on the board
unnamed 105: U1.50 (IO6(LA_row_clk__ser_tx)), U1.IO6 (IO6(LA_row_clk__ser_tx)); also elsewhere on the board
unnamed 106: U1.51 (IO5(mprj_io[5]_ser_rx)), U1.IO5 (IO5(mprj_io[5]_ser_rx)); also elsewhere on the board
unnamed 107: U1.52 (IO4(mprj_io[4]_SCK)), U1.IO4 (IO4(mprj_io[4]_SCK)); also elsewhere on the board
unnamed 108: U1.53 (IO3(mprj_io[3]_CSB)), U1.IO3 (IO3(mprj_io[3]_CSB)); also elsewhere on the board
unnamed 109: U1.54 (IO2(mprj_io[2]_SDI)), U1.IO2 (IO2(mprj_io[2]_SDI)); also elsewhere on the board
unnamed 110: U1.55 (IO1(mprj_io[1]_SDO)), U1.IO1 (IO1(mprj_io[1]_SDO)); also elsewhere on the board
unnamed 111: U1.Vdda; also elsewhere on the board
unnamed: U3.1 (XCSI), Y1.1
unnamed: U3.2 (XCSO), Y1.3
UART_EN: J7.2, R9.2, R16.2, U3.21 (ACBUS0), U5.1 (~OE), U7.1 (~OE)
USB_CS1: U3.16 (ADBUS3); also elsewhere on the board
USB_SCK_TXD: U3.13 (ADBUS0), U7.2 (A); also elsewhere on the board
USB_SI: U3.15 (ADBUS2); also elsewhere on the board
USB_SO_RXD: U3.14 (ADBUS1), U5.4 (Y); also elsewhere on the board
gpio: D1.1 (K); also elsewhere on the board
mprj_io[5]_ser_rx: J8.2, U7.4 (Y); also elsewhere on the board
ser_tx: J8.3, U5.2 (A); also elsewhere on the board
vccd: C14.2, J6.1, J6.2, U2.4 (VOUT); also elsewhere on the board
xclk: X1.3 (OUT); also elsewhere on the board
~MEM_HOLD: J9.4, R15.1, U6.7 (~HOLD(D3))
~MEM_WP: J9.3, R12.1, U6.3 (~WP(D2))
~MR: SW1.1, U4.4 (~MR)
~RST: U4.1 (~RST); also elsewhere on the board

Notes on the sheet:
Serial Display
LED and RST Switch
Flash memory interface with Caravel
Power on Reset
Flash memory
Memory testing
FTDI interface with HKSPI
TAR5S33UTE85LF
Voltage Regulator
FTDI Module
USB Module
TAR5S18U
MEMS Oscillator
Buffers to enable FTDI UART interface

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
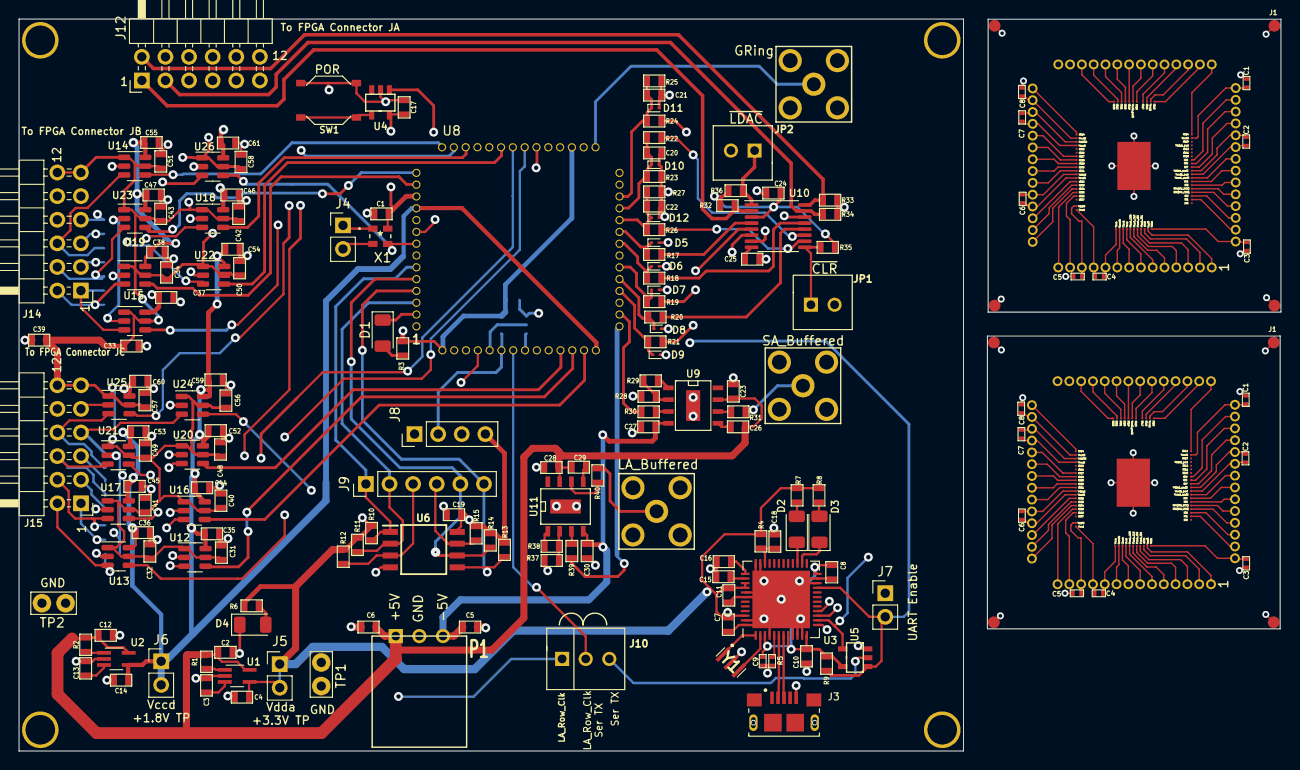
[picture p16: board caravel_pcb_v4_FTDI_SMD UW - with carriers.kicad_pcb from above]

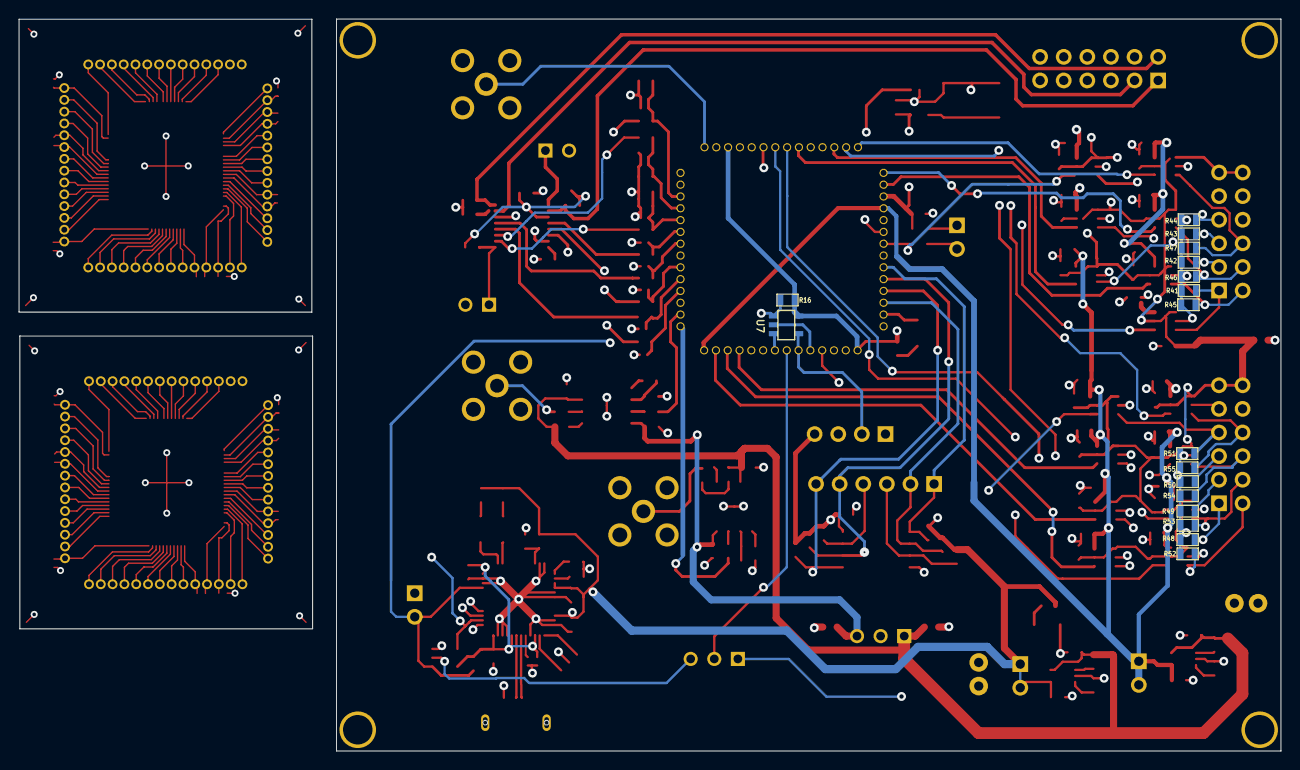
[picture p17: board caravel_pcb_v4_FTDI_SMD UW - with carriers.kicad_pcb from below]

Board: 4 copper layers, 135.7 x 78.7 mm, 206 parts (17 on the bottom side), 171 nets.

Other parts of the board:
C1#2, C7#3, C8#2: 0.1uf - CC0805KRX7R9BB104; SM0603
C1#3, C2#3, C3#2, C3#3, C4#3, C5#2, C6#3, C7#2, C8#3: 0.1uF; SM0402
C2#2: 1uf - CC0805KKX5R8BB105; SM0603
C4#2: 10uf - CC0805KKX5R8BB106; SM0603
C5#3, C6#2: 10uF; SM0603
J1, J1#2, J2, J2#2, J3#2, J3#3, J4#2, J4#3: Shield_Pad; .050_Pad_TP
U1#2: TAR5SxxU_SOT353F; SOT-353_SC-70-5_Handsoldering
U1#3: Caravel_Carrier

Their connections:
/Vdda: C3#2.1, C3#3.1, U1#3.56 (Vdda); also elsewhere on the board
unnamed 62: U1#3.VssIO; also elsewhere on the board
unnamed 63: U1#3.6 (Flash_CSB(Caravel_CSB)), U1#3.Flash_CSB (Flash_CSB(Caravel_CSB)); also elsewhere on the board
unnamed 64: U1#3.Vssd; also elsewhere on the board
unnamed 65: U1#3.8 (Clock(Caravel_SCK)), U1#3.Clock (Clock(Caravel_SCK)); also elsewhere on the board
unnamed 66: U1#3.9 (Resetb(~RST)), U1#3.Resetb (Resetb(~RST)); also elsewhere on the board
unnamed 67: U1#3.Vssa; also elsewhere on the board
unnamed 68: U1#3.Vccd; also elsewhere on the board
unnamed 69: U1#3.VddIO; also elsewhere on the board
unnamed 70: U1#3.13 (IO36(SA_col_sel0)), U1#3.IO36 (IO36(SA_col_sel0)); also elsewhere on the board
unnamed 71: U1#3.14 (IO35(SA_col_sel1)), U1#3.IO35 (IO35(SA_col_sel1)); also elsewhere on the board
unnamed 72: U1#3.15 (IO34(SA_col_sel2)), U1#3.IO34 (IO34(SA_col_sel2)); also elsewhere on the board
unnamed 73: U1#3.16 (IO33(SA_row_sel0)), U1#3.IO33 (IO33(SA_row_sel0)); also elsewhere on the board
unnamed 74: U1#3.17 (IO32(SA_row_sel1)), U1#3.IO32 (IO32(SA_row_sel1)); also elsewhere on the board
unnamed 75: U1#3.Vssd2; also elsewhere on the board
unnamed 76: U1#3.Vdda2; also elsewhere on the board
unnamed 77: U1#3.20 (IO31(SA_row_sel2)), U1#3.IO31 (IO31(SA_row_sel2)); also elsewhere on the board
unnamed 78: U1#3.21 (IO30(LA__col_data_in)), U1#3.IO30 (IO30(LA__col_data_in)); also elsewhere on the board
unnamed 79: U1#3.22 (IO29(LA_col_rst)), U1#3.IO29 (IO29(LA_col_rst)); also elsewhere on the board
unnamed 80: U1#3.23 (IO28(LA_col_ena)), U1#3.IO28 (IO28(LA_col_ena)); also elsewhere on the board
unnamed 81: U1#3.24 (IO27(LA_col_clk)), U1#3.IO27 (IO27(LA_col_clk)); also elsewhere on the board
unnamed 82: U1#3.Vssa2; also elsewhere on the board
unnamed 83: U1#3.VddIO_2; also elsewhere on the board
unnamed 84: U1#3.Vccd2; also elsewhere on the board
unnamed 85: U1#3.28 (IO24(Gring)), U1#3.IO24 (IO24(Gring)); also elsewhere on the board
unnamed 86: U1#3.31 (IO23(CSA_VREF)), U1#3.IO23 (IO23(CSA_VREF)); also elsewhere on the board
unnamed 87: U1#3.32 (IO22(VREF)), U1#3.IO22 (IO22(VREF)); also elsewhere on the board
unnamed 88: U1#3.33 (IO21(VBIAS)), U1#3.IO21 (IO21(VBIAS)); also elsewhere on the board
unnamed 89: U1#3.34 (IO20(SF_IB)), U1#3.IO20 (IO20(SF_IB)); also elsewhere on the board
unnamed 90: U1#3.35 (IO19(NB1)), U1#3.IO19 (IO19(NB1)); also elsewhere on the board
unnamed 91: U1#3.VssIO_pad2; also elsewhere on the board
unnamed 92: U1#3.37 (IO18(NB2)), U1#3.IO18 (IO18(NB2)); also elsewhere on the board
unnamed 93: U1#3.38 (IO17(OUT_IB)), U1#3.IO17 (IO17(OUT_IB)); also elsewhere on the board
unnamed 94: U1#3.39 (IO16(AMP_IB)), U1#3.IO16 (IO16(AMP_IB)); also elsewhere on the board
unnamed 95: U1#3.Vssa1; also elsewhere on the board
unnamed 96: U1#3.41 (IO15(SA_output)), U1#3.IO15 (IO15(SA_output)); also elsewhere on the board
unnamed 97: U1#3.42 (IO14(LA_output)), U1#3.IO14 (IO14(LA_output)); also elsewhere on the board
unnamed 98: U1#3.Vccd1; also elsewhere on the board
unnamed 99: U1#3.44 (IO9(LA_row_data_in)), U1#3.IO9 (IO9(LA_row_data_in)); also elsewhere on the board
unnamed 100: U1#3.45 (IO8(LA_row_rst)), U1#3.IO8 (IO8(LA_row_rst)); also elsewhere on the board
unnamed 101: U1#3.46 (IO7(LA_row_ena)), U1#3.IO7 (IO7(LA_row_ena)); also elsewhere on the board
unnamed 102: U1#3.Vdda1_pad2; also elsewhere on the board
unnamed 103: U1#3.Vssd1_pad; also elsewhere on the board
unnamed 104: U1#3.Vssa1_pad2; also elsewhere on the board
unnamed 105: U1#3.50 (IO6(LA_row_clk__ser_tx)), U1#3.IO6 (IO6(LA_row_clk__ser_tx)); also elsewhere on the board
unnamed 106: U1#3.51 (IO5(mprj_io[5]_ser_rx)), U1#3.IO5 (IO5(mprj_io[5]_ser_rx)); also elsewhere on the board
unnamed 107: U1#3.52 (IO4(mprj_io[4]_SCK)), U1#3.IO4 (IO4(mprj_io[4]_SCK)); also elsewhere on the board
unnamed 108: U1#3.53 (IO3(mprj_io[3]_CSB)), U1#3.IO3 (IO3(mprj_io[3]_CSB)); also elsewhere on the board
unnamed 109: U1#3.54 (IO2(mprj_io[2]_SDI)), U1#3.IO2 (IO2(mprj_io[2]_SDI)); also elsewhere on the board
unnamed 110: U1#3.55 (IO1(mprj_io[1]_SDO)), U1#3.IO1 (IO1(mprj_io[1]_SDO)); also elsewhere on the board
unnamed 111: U1#3.Vdda; also elsewhere on the board

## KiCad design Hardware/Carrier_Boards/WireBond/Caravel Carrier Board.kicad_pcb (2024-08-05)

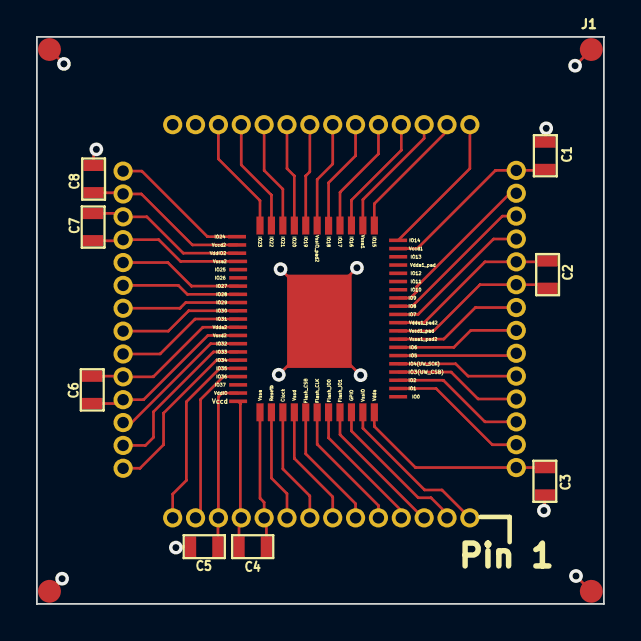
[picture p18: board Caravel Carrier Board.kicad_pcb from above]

Board: 4 copper layers, 31.5 x 31.5 mm, 13 parts (0 on the bottom side), 46 nets.

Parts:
C1, C2, C3, C4, C5, C6, C7, C8: 0.1uF; SM0603
J1, J2, J3, J4: Shield_Pad; .050_Pad_TP
U1: Caravel_Carrier

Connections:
/Vccd: C4.1, U1.11 (Vccd), U1.Vccd
/Vccd1: C1.1, U1.43 (Vccd1), U1.Vccd1
/Vccd2: C8.1, U1.27 (Vccd2), U1.Vccd2
/VddIO: C5.1, U1.12 (VddIO), U1.VddIO
/VddIO_2: C7.1, U1.26 (VddIO_2), U1.VddIO_2
/Vdda: C3.1, U1.56 (Vdda), U1.Vdda
/Vdda1: C2.1, U1.47 (Vdda1_pad2), U1.Vdda1_pad2
/Vdda2: C6.1, U1.19 (Vdda2), U1.Vdda2
GND: C1.2, C2.2, C3.2, C4.2, C5.2, C6.2, C7.2, C8.2, J1.1, J2.1, J3.1, J4.1, U1.1 (VssIO), U1.7 (Vssd), U1.10 (Vssa), U1.18 (Vssd2), U1.25 (Vssa2), U1.36 (VssIO_pad2), U1.40 (Vssa1), U1.48 (Vssd1_pad), U1.49 (Vssa1_pad2), U1.GND (Substrate_GND), U1.VssIO, U1.VssIO_pad2, U1.Vssa, U1.Vssa1, U1.Vssa1_pad2, U1.Vssa2, U1.Vssd, U1.Vssd1_pad, U1.Vssd2
unnamed: U1.8 (Clock(Caravel_SCK)), U1.Clock (Clock(Caravel_SCK))
unnamed: U1.5 (Flash_CLK), U1.Flash_CLK
unnamed: U1.6 (Flash_CSB(Caravel_CSB)), U1.Flash_CSB (Flash_CSB(Caravel_CSB))
unnamed: U1.4 (Flash_IO0(Caravel_D0)), U1.Flash_IO0 (Flash_IO0(Caravel_D0))
unnamed: U1.3 (Flash_IO1(Caravel_D1)), U1.Flash_IO1 (Flash_IO1(Caravel_D1))
unnamed: U1.2 (GPIO), U1.GPIO
unnamed: U1.55 (IO1(mprj_io[1]_SDO)), U1.IO1 (IO1(mprj_io[1]_SDO))
unnamed: U1.54 (IO2(mprj_io[2]_SDI)), U1.IO2 (IO2(mprj_io[2]_SDI))
unnamed: U1.53 (IO3(mprj_io[3]_CSB)), U1.IO3 (IO3(mprj_io[3]_CSB))
unnamed: U1.52 (IO4(mprj_io[4]_SCK)), U1.IO4 (IO4(mprj_io[4]_SCK))
unnamed: U1.51 (IO5(mprj_io[5]_ser_rx)), U1.IO5 (IO5(mprj_io[5]_ser_rx))
unnamed: U1.50 (IO6(LA_row_clk__ser_tx)), U1.IO6 (IO6(LA_row_clk__ser_tx))
unnamed: U1.46 (IO7(LA_row_ena)), U1.IO7 (IO7(LA_row_ena))
unnamed: U1.45 (IO8(LA_row_rst)), U1.IO8 (IO8(LA_row_rst))
unnamed: U1.44 (IO9(LA_row_data_in)), U1.IO9 (IO9(LA_row_data_in))
unnamed: U1.42 (IO14(LA_output)), U1.IO14 (IO14(LA_output))
unnamed: U1.41 (IO15(SA_output)), U1.IO15 (IO15(SA_output))
unnamed: U1.39 (IO16(AMP_IB)), U1.IO16 (IO16(AMP_IB))
unnamed: U1.38 (IO17(OUT_IB)), U1.IO17 (IO17(OUT_IB))
unnamed: U1.37 (IO18(NB2)), U1.IO18 (IO18(NB2))
unnamed: U1.35 (IO19(NB1)), U1.IO19 (IO19(NB1))
unnamed: U1.34 (IO20(SF_IB)), U1.IO20 (IO20(SF_IB))
unnamed: U1.33 (IO21(VBIAS)), U1.IO21 (IO21(VBIAS))
unnamed: U1.32 (IO22(VREF)), U1.IO22 (IO22(VREF))
unnamed: U1.31 (IO23(CSA_VREF)), U1.IO23 (IO23(CSA_VREF))
unnamed: U1.28 (IO24(Gring)), U1.IO24 (IO24(Gring))
unnamed: U1.24 (IO27(LA_col_clk)), U1.IO27 (IO27(LA_col_clk))
unnamed: U1.23 (IO28(LA_col_ena)), U1.IO28 (IO28(LA_col_ena))
unnamed: U1.22 (IO29(LA_col_rst)), U1.IO29 (IO29(LA_col_rst))
unnamed: U1.21 (IO30(LA__col_data_in)), U1.IO30 (IO30(LA__col_data_in))
unnamed: U1.20 (IO31(SA_row_sel2)), U1.IO31 (IO31(SA_row_sel2))
unnamed: U1.17 (IO32(SA_row_sel1)), U1.IO32 (IO32(SA_row_sel1))
unnamed: U1.16 (IO33(SA_row_sel0)), U1.IO33 (IO33(SA_row_sel0))
unnamed: U1.15 (IO34(SA_col_sel2)), U1.IO34 (IO34(SA_col_sel2))
unnamed: U1.14 (IO35(SA_col_sel1)), U1.IO35 (IO35(SA_col_sel1))
unnamed: U1.13 (IO36(SA_col_sel0)), U1.IO36 (IO36(SA_col_sel0))
unnamed: U1.9 (Resetb(~RST)), U1.Resetb (Resetb(~RST))

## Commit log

2024-08-03 add some test board files
2024-08-05 added hardware files
    [Caravel Carrier Board.kicad_pcb, Caravel M.2 card adapter to UW Caravel test board.kicad_pcb, Level Shifters.kicad_sch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]
2024-08-05 directory add
    [caravel_pcb_v4_FTDI_SMD UW - with carriers.kicad_pcb, caravel_pcb_v4_FTDI_SMD UW_ni.kicad_pcb]
2024-10-22 adapter boards for vacuum feedthrough
    [feedthrough_adapter.kicad_pcb, feedthrough_adapter.kicad_sch, vac_side_adapter.kicad_pcb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]
2024-10-22 carrier board

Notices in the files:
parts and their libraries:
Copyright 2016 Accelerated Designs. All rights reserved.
